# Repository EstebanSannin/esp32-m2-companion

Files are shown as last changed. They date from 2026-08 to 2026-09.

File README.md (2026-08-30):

<p align="center">
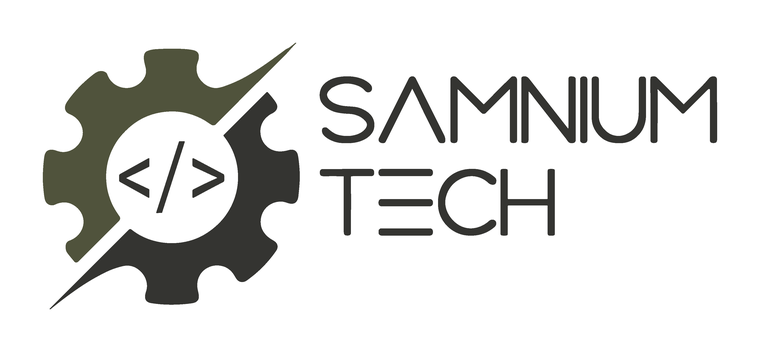
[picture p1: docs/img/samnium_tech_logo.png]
Samnium Tech
  
</p>

# esp32-m2-companion

M.2 Key-B 2242 card with an ESP32-S3-WROOM-1 acting as a USB companion MCU
for embedded Linux hosts. Spec: [SPEC.md](SPEC.md) (contract, frozen v1).

<p align="center">
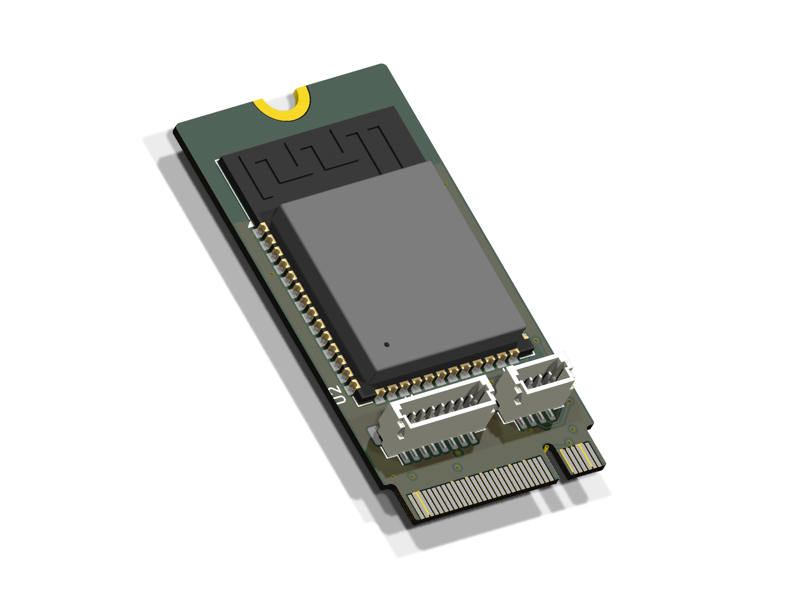
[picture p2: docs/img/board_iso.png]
3D render of the routed card
  
</p>
<p align="center"><sub>
  Generated render of the routed board · <a href="docs/img/board_top.png">top</a> ·
  <a href="docs/img/board_bottom.png">bottom</a> (silk logo) · regenerate with <code>make render</code>
</sub></p>

**[→ Product datasheet](DATASHEET.md)** — features, specs, pinout, recovery interface.
**[→ Layer stackup & routing](docs/stackup.md)** — 4-layer stack, impedance, per-layer copper views.
**[→ Interactive 3D viewer](https://estebansannin.github.io/esp32-m2-companion/3d/viewer.html)**
(GitHub Pages; or download [docs/3d/viewer.html](docs/3d/viewer.html) — fully
offline, GLB embedded) · [STEP](docs/3d/esp32_m2_companion.step) /
[GLB](docs/3d/esp32_m2_companion.glb) for MCAD · regenerate with `make 3d`.

**Open source hardware** — © 2026 Stefano Viola, licensed under
[CERN-OHL-P v2](LICENSE). Designed by Stefano Viola with Claude (Anthropic);
schematic-as-code in SKiDL, all outputs generated (`make check`, `make sch`,
`make svg`). The vendored M.2 card-edge footprint derives from
[timonsku/M.2-Card-Footprints](https://github.com/timonsku/M.2-Card-Footprints)
(CERN-OHL-P v2).

Current phase: **Phase 2 — Layout** (GATEs 1–2 passed). Owner routes
[hardware/kicad/esp32_m2_companion.kicad_pcb](hardware/kicad/esp32_m2_companion.kicad_pcb);
open items in [docs/layout-notes.md](docs/layout-notes.md).

## Host compatibility

| Host | Status |
|---|---|
| Toradex Mallow (Verdin) M.2 Key-B slot | Primary target — pin mapping verified against Mallow V1.1 datasheet |
| Raspberry Pi 5 + Waveshare "PCIe TO 4G/5G M.2 USB3.2 HAT+" | Nice-to-have (ADR 0004) — HAT officially fits 3042/3052 (2242 standoff TBD), sideband wiring unpublished |
| Raspberry Pi official M.2 HAT+ | **NOT compatible** — M-key, PCIe only, no USB on the socket |

## Layout

- `docs/datasheets/` — all reference documents (provenance in its README)
- `docs/pinmap.md` — M.2 edge + ESP32-S3 pin allocation (GATE 1)
- `docs/decisions/` — ADRs
- `docs/risks.md` — risk register
- `docs/environment.md` — tool install log
- `hardware/` — schematic-as-code + KiCad (Phase 1+)
- `firmware/` — ESP-IDF project (Phase 4)

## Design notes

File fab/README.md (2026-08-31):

# Fab package — JLCPCB upload files

Generated by `make fab` (regenerates from the routed board). Upload these 3 to
JLCPCB's [instant quote](https://cart.jlcpcb.com/quote):

| File | JLCPCB slot |
|---|---|
| `esp32_m2_companion_gerbers.zip` | **Gerber file** (PCB tab) |
| `esp32_m2_companion_bom_jlc.csv` | **BOM** (SMT Assembly tab) — Comment / Designator / Footprint / LCSC# |
| `esp32_m2_companion_cpl_jlc.csv` | **CPL / centroid** (SMT Assembly tab) — 22 placed parts |

## Order settings (v1) — confirmed against JLCPCB quote UI 2026-08-30
- **Layers 4**, thickness **0.8 mm**
- **Specify Stackup: Yes → JLC04081H-3313** (Standard, 0.80 mm, prepreg 3313
  RC57% 0.0994 mm). This alone locks the geometry that sets the USB impedance.
- **Impedance Control: No requirement** (i.e. OFF). Deliberate: JLC charges
  ~€28 for it, and the ESP32-S3 USB is Full-Speed (12 Mbps) only — controlled
  impedance is functionally irrelevant. The stackup spec above already pins the
  0.0994 mm prepreg, and the verified 0.14 mm traces give ~88 Ω regardless
  (see docs/stackup.md). The paid option only buys a TDR measurement, not a
  different board.
- Surface finish **ENIG**.
- **Gold Fingers: Yes** (hard gold on the M.2 edge contacts — accepted at our
  size, no visible upcharge; proper wear finish for a plug-in edge).
- **Beveling: No** — forced. JLC UI: *"Beveled fingers cannot be produced for
  PCBs smaller than 50mm x 50mm."* Our card is 22×42. **Consequence:** square
  90° finger edge. Before first insertion, lightly **hand-chamfer the leading
  edge** (~45°, ~0.2–0.3 mm, both faces, leading corner only — do not sand the
  contact tips) so it seats without stressing the host M.2 socket.
- Confirm Production File: **Yes**; Deburring/Edge rounding: Yes; Mark: Remove.
- **Assembly: both sides**, 5 pcs
- 7 Extended parts (feeder fee ~$3 each): U2 module, U1 USBLC6 (ST C7519), D1/D2 BAT54A, J3/J4 JST SH
- DNP (not placed): R5, R6, C8, C9 — already excluded from the CPL

Do not order before GATE 3 (colleague review). See docs/layout-notes.md, docs/review-findings.md.

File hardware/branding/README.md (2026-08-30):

# Branding — silkscreen label

Bottom-side silk label placed in the top strip of the card (under the M.2
mounting hole, above C6/C7 — a component-free area).

- `logo_samnium_tech.png` — source logo (samnium.tech, `logo_samnium_tech_no_bg_no_name.png`,
  3167×1255, fetched 2026-08-30). Owner-supplied company logo.
- `gen_logo_silk.py` — crops the gear logomark (drops the wordmark), thresholds
  to 1-bit, emits `logo_silk_rects.json` (run-length silk rectangles, ~3.8×4 mm).
  Run: `uv run --no-project --with pillow python hardware/branding/gen_logo_silk.py`
- `logo_silk_rects.json` — committed so the silk is regenerable without Pillow.
- Applied to the board by `../tools/add_silk.py` (grouped as `silk_label`,
  idempotent — safe to re-run; never touches copper/routing).

Text lines: `ESP32-M2-COMPANION` / `v1.0  Stefano Viola` / `2026-08` (0.8 mm).

Note: the diagonal brand slash is ~0.1–0.15 mm at 3.8 mm — at silk's limit, may
print faint. The gear teeth and `</>` are above the 0.15 mm floor.

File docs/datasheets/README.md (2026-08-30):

# Datasheet provenance

All pin assignments in `docs/pinmap.md` trace to these files. Fetched
2026-08-28 unless noted.

| File | Source URL | Version | Used for |
|---|---|---|---|
| `mallow-carrier-board-datasheet.pdf` | https://docs.toradex.com/113873-mallow-carrier-board-datasheet.pdf | Mallow V1.1 datasheet | **Primary host.** M.2 X17 pin table (Table 10, pp. 15–17), X16 secondary extension header (Table 22, pp. 27–28), USB hub topology (§2.5.2), power rails (Table 4) |
| `esp32-s3-wroom-1_wroom-1u_datasheet_en.pdf` | https://www.espressif.com/sites/default/files/documentation/esp32-s3-wroom-1_wroom-1u_datasheet_en.pdf | v1.8 | Module pin definitions (Table 3-1, pp. 11–12), strapping pins (§4, pp. 13–14), variant comparison (Table 1-1, p. 3) |
| `esp32-s3_hardware_design_guidelines_en.pdf` | https://docs.espressif.com/projects/esp-hardware-design-guidelines/en/latest/esp32s3/esp-hardware-design-guidelines-en-master-esp32s3.pdf | release `master` (rolling) | EN/CHIP_PU reset timing + RC (10 kΩ/1 µF) §1.3.3, decoupling & 4-layer power layout, antenna keep-out |
| `quectel_rm50xq_hardware_design_v1.2.pdf` | https://sixfab.com/wp-content/uploads/2022/05/Quectel_RM50xQ_Series_Hardware_Design_V1.2.pdf | V1.2 (2022-01-27) | **M.2 Key-B WWAN socket pinout reference** (Figure 2 p. 22, Table 8 pp. 23+). The PCI-SIG M.2 EM spec is paywalled; this is the canonical WWAN-card usage of the socket, cross-checked pin-for-pin against Mallow Table 10 |
| `usblc6-2sc6.pdf` | https://media.digikey.com/pdf/Data%20Sheets/UTD%20Semi%20PDFs/USBLC6-2SC6.pdf | UMW (友台) clone datasheet | USBLC6-2SC6 pinout/ratings. **NOT the ST original** — st.com and mouser.com are blocked from this machine. Pin-compatible; UMW part is itself an LCSC BOM candidate (C323793). Owner to supply ST original if ST part (LCSC C7519) is chosen |
| `waveshare_pcie-to-4g5g-m2-usb32-hatplus_wiki_snapshot.html` | https://www.waveshare.com/wiki/PCIe_TO_4G/5G_M.2_USB3.2_HAT+ | wiki snapshot | Secondary host (RPi5 HAT). **No board schematic is published.** Wiki confirms: 3042/3052 module support (no 2242 standoff mentioned), onboard reset button, SIM7600-M.2 (USB2-only modem) supported ⇒ USB 2.0 D+/D− wired to socket |

## Missing / unobtainable

- **TOGIALED TJ-S1706SW6T side-view LED drawing** — LCSC datasheet mirror
  blocks direct download from this machine. Needed at GATE 3 for the land
  pattern + emitting-face orientation (currently 0603 placeholder). Grab it
  from the LCSC product pages (C273612 / C273616) in a browser.

- **ST USBLC6-2 original datasheet** — st.com unreachable from here.
- **Waveshare HAT+ schematic** — not published; M.2 sideband wiring on that
  board is unknown (recovery there is best-effort per SPEC §10.6).
- **PCI-SIG M.2 (NGFF) electromechanical spec** — paywalled; mechanical
  card-outline data for Phase 2 will need a licensed copy or a derived
  reference (flagged for GATE 1).

## Added during Phase 2 (2026-08-28)

| File | Source URL | Used for |
|---|---|---|
| `amphenol_mdt420b01001_m2_socket.pdf` | via JLCPCB part page C4594496 (Amphenol ICC product brief) | Mallow's M.2 socket: ratings, durability. NOTE: no mating-card drawing — product brief only |
| `m2_em_spec_rev1.0_2013_archive.pdf` | archive.org copy (via timonsku/M.2-Card-Footprints README) of PCI-SIG "PCIe M.2 Electromechanical Spec Rev 1.0" (2013) | Card mechanical geometry: 2242 outline, gold-finger dimensions, notch position, bevel. Rev 1.0 (current spec is newer) — fine for mechanical card data; resolves risk R8 |
| `togialed_tj-s1706_sideview.pdf` | LCSC datasheet repository (C273616) | D3/D4 side-view LED land pattern (0.80×0.70, 1.80 mm c-c), polarity (pin 1 = cathode), package geometry. Drove the custom `LED_TJ-S1706_SideView` footprint |

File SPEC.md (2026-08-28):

# ESP32-S3 M.2 Companion Card — Project Specification (v1.0)

Project codename: `esp32-m2-companion`
Owner: Stefano · Design agent: Claude (Claude Code session)
Status: spec frozen for v1 — changes require owner approval

---

## 1. Concept

A small M.2 Key-B 2242 card carrying an ESP32-S3 module, acting as a
**companion microcontroller** for embedded Linux hosts. The host talks to it
over the USB 2.0 lines available on the M.2 connector; the card offloads
realtime / GPIO / sensor work the Linux side is bad at. WiFi/BLE come for free
from the module.

Design philosophy: **hardware-as-code**. Schematic captured in a code-based
tool, verified with headless ERC/DRC, versioned in git, reviewed by the owner
at defined gates before any money is spent.

## 2. Goals (v1)

- G1. Enumerate as a USB CDC device on the host immediately after insertion.
- G2. Firmware fully replaceable **from the host**, including recovery of a
  bricked card, with no physical button access.
- G3. Expose usable IO on a card-edge header: GPIO, I2C, UART, SPI-capable pins.
- G4. Status LED controllable from firmware + power indicator LED.
- G5. WiFi/BLE functional via the module's integrated antenna (best-effort in
  v1: correct keep-out and placement, no formal RF validation).
- G6. Fully assembled by JLCPCB (SMT service); owner only plugs it in.
- G7. Reusable block structure so a radio-less RP2350 sibling card can be
  derived later by swapping only the MCU block.

## 3. Non-goals (v1)

- No PCIe, no SATA, no SIM interface.
- No battery, no external power input: card is powered only from M.2 3.3V.
- No RF certification work, no antenna tuning.
- No enclosure / thermal design.
- No level shifting beyond 3.3V IO (hosts with 1.8V GPIO banks interact via
  USB, not via the header).

## 4. Target hosts

| Host | Slot | Status |
|---|---|---|
| Toradex Mallow carrier (Verdin family) | On-board M.2 Key-B, 30/42/52 mm cards, intended for modems | Primary target. **Verify from datasheet** which pins carry USB 2.0 and which sideband signals (W_DISABLE#, RESET#, FULL_CARD_POWER_OFF#, …) are wired to SoM GPIOs. Datasheet: https://docs.toradex.com/113873-mallow-carrier-board-datasheet.pdf |
| Raspberry Pi 5 + third-party Key-B modem HAT (e.g. Waveshare "PCIe to M.2 4G/5G + USB 3.2 HAT") | Key-B slot with USB wired (modem slot) | Secondary target. Official RPi M.2 HAT+ is M-key/PCIe-only → NOT compatible, document this clearly in README. **Verify** the chosen HAT provides USB 2.0 (not only USB 3) on the socket and has a standoff position at 42 mm. |

## 5. Form factor & fabrication constraints

- M.2 module, **Key B**, size **2242** (22 × 42 mm), single-sided component
  placement on top preferred (bottom side allowed for passives if needed —
  check socket clearance class in M.2 spec).
- PCB thickness **0.8 mm** (M.2 requirement — not 1.6 mm!).
- Edge connector: gold fingers per M.2 spec geometry, **ENIG/hard-gold finger
  option + 45° edge bevel** must be selected at JLCPCB order time. Confirm
  JLCPCB supports gold fingers on 0.8 mm 4-layer — adjust stackup if not.
- Layer count: 4 layers (SIG / GND / PWR / SIG) — makes USB diff-pair
  referencing and RF keep-out trivial; cost difference at JLCPCB is small.
- Design rules: JLCPCB standard capability (≥ 5/5 mil trace/space to be safe,
  ≥ 0.3 mm drill, their published rules imported into KiCad as DRC profile).
- All components chosen from **LCSC catalog**, preferring JLCPCB **Basic
  parts**; every Extended part must be flagged in the BOM with justification.
- Card mounting notch centered at top edge per M.2 mechanical drawing.

## 6. Hardware architecture

### 6.1 MCU
- **ESP32-S3-WROOM-1-N8R2** (8 MB flash, 2 MB PSRAM). If N8R2 has poor LCSC
  stock, N8 or N16R8 acceptable — flag for approval.
- Module PCB antenna located at the **top card edge** (away from the M.2
  connector), with copper/ground keep-out under the antenna area per
  Espressif's hardware design guidelines. Antenna may overhang the 42 mm edge
  only if the mounting standoff geometry still works — otherwise inboard with
  keep-out.

### 6.2 Power
- 3.3V taken directly from M.2 3.3V rail (rated for modem-class loads —
  budget ≥ 1 A available; ESP32-S3 WiFi TX bursts ~500 mA peak).
- **No regulator in v1.** Input filtering: ferrite bead or 0Ω + bulk
  (≥ 2 × 22 µF ceramic or 47–100 µF) + per-pin 100 nF decoupling per
  Espressif guidelines.
- Power LED (green) on 3.3V rail with suitable series resistor.

### 6.3 USB
- M.2 USB 2.0 D+/D− routed directly to ESP32-S3 native USB pins
  (GPIO19/GPIO20). Pin numbers of USB on the Key-B edge connector must be
  taken from the **M.2 specification pinout, verified against the Mallow
  datasheet** — never from memory.
- 90 Ω differential pair routing, length-matched, solid ground reference,
  no stubs. USB-FS (12 Mbps) is forgiving but do it properly.
- ESD protection: USBLC6-2SC6 or equivalent LCSC-stocked TVS array on D+/D−,
  placed close to the edge connector.

### 6.4 Host-controlled recovery (critical requirement)
- ESP32-S3 **EN** and **GPIO0 (BOOT)** each wired to an M.2 sideband pin
  (candidates: RESET#, W_DISABLE1#, FULL_CARD_POWER_OFF# — final choice
  driven by what Mallow actually wires to SoM GPIOs and what the RPi HAT
  exposes; document the mapping).
- Sideband inputs treated as open-drain with on-card pull-ups to 3.3V, so an
  unconnected sideband = normal boot. RC on EN per Espressif reset timing.
- Resulting recovery flow (document in README):
  `host gpioset BOOT=0, pulse EN` → ROM bootloader → `esptool.py` over the
  same USB → flash → release. Normal flow: esptool auto-reset over
  USB-Serial-JTAG, no GPIO needed.

### 6.5 Status LED
- One firmware-controlled LED on a module GPIO (active-low, series resistor).
  Optional (owner may approve): WS2812B-2020 instead, single data GPIO.

### 6.6 IO header
- 2.54 mm pitch, single row, along the long card edge (top side), **unpopulated**
  (JLCPCB assembles SMD; owner can solder a header when needed — or select
  their through-hole assembly if trivial).
- Signals (~12 pins): 3.3V, GND, 1× I2C (SDA/SCL with footprints for optional
  pull-ups, DNP by default), 1× UART (TX/RX), 4–6 × GPIO chosen so that at
  least one full SPI set is available among them. Choose GPIOs avoiding
  strapping pins and octal-PSRAM-reserved pins (GPIO35-37 on R8 variants —
  check per chosen module variant).
- Silkscreen label every pin.

### 6.7 Things deliberately absent
- No USB-C debug connector (host USB is the debug port). If layout has spare
  room, test points for EN/BOOT/TX/RX/3V3/GND are welcome.

## 7. Firmware (v1 bring-up)

ESP-IDF (latest stable) project in `firmware/`:
- USB CDC console (USB-Serial-JTAG) with a trivial command shell:
  `led on|off|blink`, `gpio read|write <n>`, `i2cdetect`, `info` (chip ID,
  reset reason, firmware version).
- Blink task on the status LED as heartbeat.
- WiFi station connect + `ping` demo behind a config flag (proves radio).
- Makefile/justfile targets: `build`, `flash` (esptool over /dev/ttyACMx),
  `recover-flash` (gpioset sequence documented per host).

## 8. Toolchain & environment

- Work happens on the owner's server (`m920x`), account already provisioned.
  Claude may install tools (apt/pip) as needed — keep an
  `docs/environment.md` log of everything installed.
- **KiCad 9** + `kicad-cli` for headless ERC/DRC/exports.
- Schematic-as-code: **atopile** preferred; fall back to **SKiDL** if atopile's
  component/footprint availability blocks progress. Decision documented in
  `docs/decisions/0001-hdl-tool.md` (keep ADRs for major choices).
- Layout: interactive work is the owner's; Claude prepares placement
  suggestions, net classes (USB diff pair 90 Ω), DRC profile, and reviews the
  routed board by parsing the `.kicad_pcb` file.
- JLCPCB DRC rule set imported; CI (even a simple `make check`) runs
  ERC + DRC + BOM-vs-LCSC availability check on every commit.
- Outputs for ordering: Gerbers (JLCPCB naming), drill files, BOM (LCSC part
  numbers), CPL/pick-and-place, assembly drawings.

## 9. Workflow & review gates

Claude works autonomously **within a phase**, stops at every gate for owner
review. Never proceed past a gate without explicit approval.

- **Phase 0 — Groundwork.** Fetch and store in `docs/datasheets/`: Mallow
  datasheet, ESP32-S3-WROOM-1 datasheet, ESP32-S3 hardware design guidelines,
  M.2 (NGFF) Key-B pinout reference, USBLC6 datasheet, candidate RPi5 HAT
  wiki/schematic. Produce `docs/pinmap.md`: full M.2 edge-pin table (pin,
  M.2 spec function, Mallow wiring, our usage) + ESP32-S3 pin allocation
  table (pin, function, strapping notes). → **GATE 1: owner reviews pinmap.**
- **Phase 1 — Schematic-as-code.** Implement blocks: `m2_connector`, `power`,
  `usb_esd`, `mcu`, `recovery`, `leds`, `header`. ERC clean. Netlist + BOM
  (all LCSC-resolved) + human-readable schematic PDF export.
  → **GATE 2: owner reviews schematic + BOM.**
- **Phase 2 — Layout.** Claude: board outline with exact M.2 2242 mechanical
  geometry + gold-finger footprint, placement proposal, net classes, DRC
  profile. Owner routes / adjusts in KiCad GUI; Claude reviews the result
  (DRC, diff-pair check, antenna keep-out check, silkscreen review).
  → **GATE 3: owner approves layout.**
- **Phase 3 — Fab package.** Gerbers/BOM/CPL, JLCPCB order checklist
  (0.8 mm, 4-layer, gold fingers + bevel, assembly side, part substitutions).
  → **GATE 4: owner places order.**
- **Phase 4 — Firmware & bring-up plan.** Firmware ready before boards
  arrive; `docs/bringup.md` = step-by-step first-power checklist (visual
  inspection, resistance checks on 3.3V, first insertion in Mallow, dmesg
  expectations, flash, LED, I2C scan, WiFi test).

## 10. Success criteria

1. Card inserted in Mallow → host `dmesg` shows Espressif USB-Serial-JTAG
   CDC device.
2. `esptool.py` flashes firmware over that port.
3. Bricked-firmware simulation (flash garbage) → recovered purely via host
   GPIO sequence + esptool.
4. Status LED heartbeat; `i2cdetect` finds a sensor wired to the header.
5. WiFi demo connects to an AP.
6. Same result on RPi5 + chosen Key-B HAT (best effort).

## 11. Known risks / open questions (track in `docs/risks.md`)

- R1. Mallow B-key USB wiring & sideband→SoM GPIO mapping unconfirmed until
  datasheet is read. (Blocks pinmap.)
- R2. JLCPCB gold fingers + bevel on 0.8 mm 4-layer: confirm capability/cost.
- R3. Antenna performance flat against a carrier board: accepted risk in v1.
- R4. 2242 card mechanical fit in 3042-oriented RPi HATs (standoff position).
- R5. GPIO choice vs. octal-PSRAM reservations on the exact WROOM variant.

## 12. Knowledge management (added 2026-08-28, owner)

1. `docs/review-findings.md` is an **append-only** log. Every finding from any
   review gate — owner's, an external senior HW designer's, or self-caught —
   gets one entry: date, phase, finding, severity, and a classification:
   - **BLOCK**: bug/improvement in a reusable circuit block → fix the block
     source and add a line to that block's `LESSONS.md`
   - **PROCESS**: workflow/tooling/fab gap → flag to owner as a candidate rule
     for the shared hardware-design skill
   - **PROJECT**: specific to this board → note it in `CLAUDE.md`
2. Schematic sources are organized as self-contained reusable blocks
   (`m2_keyb_edge`, `esp32s3_companion`, `usb_esd`, `power_3v3`, `leds`,
   `io_header`) — each block in its own directory with sources, datasheet
   references, and a `LESSONS.md` (empty is fine; the file must exist). At
   project end, stable blocks are promoted to a shared hw-blocks repo.
3. `CLAUDE.md` stays current with project conventions: net names follow the
   M.2 / Verdin datasheet naming verbatim, tool choices, DRC profile, gate
   protocol.
4. When the owner relays findings from an external senior designer review,
   their categorization ("wrong" / "works but unprofessional" / "fragile at
   scale") is preserved in the log — never flattened.

---

# Kickoff prompt for the Claude Code session

Copy-paste the following as the first message (with SPEC file placed in the
repo root as `SPEC.md`):

```
You are the hardware design engineer for this project. Read SPEC.md fully
before doing anything — it is the contract; do not deviate from it without
asking me.

Context: we are designing an M.2 Key-B 2242 card with an ESP32-S3 acting as
a USB companion MCU for embedded Linux hosts (details in SPEC.md). I am an
experienced embedded engineer; talk to me as a peer, be concise, and
challenge the spec if you find a real problem in it.

Ground rules:
1. Work phase by phase as defined in SPEC.md §9. STOP at every GATE and ask
   for my review. Within a phase, work autonomously.
2. Never trust memory for pinouts, footprints or electrical values. Every
   pin assignment must be traceable to a datasheet stored in
   docs/datasheets/. If a document can't be fetched, tell me and I'll
   provide it.
3. Everything in git: small commits, meaningful messages. Record notable
   choices as short ADRs in docs/decisions/.
4. You may install any tools you need on this machine (KiCad 9, kicad-cli,
   atopile, skidl, esp-idf, python packages). Log installs in
   docs/environment.md.
5. Every BOM line must carry an LCSC part number and Basic/Extended status.
6. After any change to schematic sources, run ERC headlessly and show me
   the result. Set this up as `make check` early.
7. If you are uncertain between two design options, present both with a
   recommendation instead of silently picking one.

Start now with Phase 0: create the repo skeleton, fetch the datasheets
listed in SPEC.md §9 Phase 0, and produce docs/pinmap.md for GATE 1 review.
```

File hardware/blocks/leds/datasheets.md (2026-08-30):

# References — leds
- ADR 0003 (+ 2026-08-29 amendment: side-view at left card edge).
- D3: TOGIALED TJ-S1706SW6TGLC2G-A5 green side-view (LCSC C273616, Extended)
- D4: TOGIALED TJ-S1706SW6TGLC2R-A5 red side-view (LCSC C273612, Extended)
- R3/R4: 330R 0603 (C23138, Basic). Green InGaN Vf(20mA) 2.8–3.4 V → runs
  ~1–2 mA at 3.3 V by design; red ~3.5 mA. Verify brightness at bring-up.
- KiCad Device:LED pin 1 = K, pin 2 = A. **RESOLVED 2026-08-30** against the
  TOGIALED datasheet (`docs/datasheets/togialed_tj-s1706_sideview.pdf`):
  - Land pattern was a 0603 placeholder (1.576 mm c-c) — too tight for the
    1.70 mm body. Replaced with custom `LED_TJ-S1706_SideView` footprint
    (pads 0.80×0.70, **1.80 mm c-c** per datasheet). DRC clean; LED-net
    connectivity preserved (old track ends stay inside the new pads).
  - Polarity confirmed: pin 1 = cathode (black-mark end, diode symbol),
    pin 2 = anode — matches KiCad Device:LED and our netlist.
  - Emit face marked on F.Fab pointing −x (out the left card edge). Caveat:
    the datasheet 2D views do NOT distinguish the two long faces, so the
    front/back emit face is the *intended* direction — **confirm on a
    physical sample at GATE 3** (low risk: 120° beam + edge placement).

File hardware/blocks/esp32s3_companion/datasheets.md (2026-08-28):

# References — esp32s3_companion
- docs/datasheets/esp32-s3-wroom-1_wroom-1u_datasheet_en.pdf v1.8
  (Table 3-1 pins, §4 strapping, Table 1-1 variants)
- docs/datasheets/esp32-s3_hardware_design_guidelines_en.pdf (decoupling)
- KiCad symbol RF_Module:ESP32-S3-WROOM-1 (pin names runtime-asserted
  against Table 3-1 in esp32s3_companion.py)

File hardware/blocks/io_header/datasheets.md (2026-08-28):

# References — io_header
- SPEC §6.6; docs/pinmap.md §2 (GPIO selection rationale)
- Unpopulated (DNP). I2C pull-up footprints 10k DNP.

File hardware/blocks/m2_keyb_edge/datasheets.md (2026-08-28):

# References — m2_keyb_edge
- docs/pinmap.md §1 (authoritative pin table for this block)
- docs/datasheets/mallow-carrier-board-datasheet.pdf Table 10 (X17)
- docs/datasheets/quectel_rm50xq_hardware_design_v1.2.pdf Fig. 2 / Table 8
- Footprint: placeholder `esp32m2:M2_KeyB_2242_EdgeFingers` — Phase 2, needs
  M.2 EM spec gold-finger geometry (risk R8)

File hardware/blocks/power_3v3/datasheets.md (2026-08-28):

# References — power_3v3
- SPEC §6.2; Espressif HDG power sections
- FB: Sunlord GZ2012D101TF (LCSC C1015, Basic) 100R@100MHz, 800 mA, 150 mR.
  Chosen over GZ2012D601TF (C1017): that one is 500 mA — too close to
  ESP32-S3 TX bursts. Alternative if bead rejected at GATE 2: 0R link.

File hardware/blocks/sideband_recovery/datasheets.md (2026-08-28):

# References — sideband_recovery
- ADR 0002 (mapping + SODIMM 244 device-tree evidence)
- docs/datasheets/lbat54a_schottky.pdf (BAT54A: pin 3 = common anode —
  note the doc TITLE wrongly says "Dual Series"; trust the drawing)
- docs/datasheets/esp32-s3_hardware_design_guidelines_en.pdf §1.3.3 (EN RC)

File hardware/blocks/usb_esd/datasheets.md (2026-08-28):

# References — usb_esd
- docs/datasheets/usblc6-2sc6.pdf (UMW clone doc; pin map p.1 —
  1=I/O1 2=GND 3=I/O2 4=I/O2 5=VBUS 6=I/O1). ST original pending (risk R7).

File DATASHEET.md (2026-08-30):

# ESP32 M.2 Companion — Datasheet

**M.2 Key-B 2242 USB companion microcontroller card**
Preliminary · rev `c5e5aa7-dirty` · 2026-08-31 · © 2026 Stefano Viola · CERN-OHL-P v2
*(generated by `make datasheet` — do not edit by hand)*

<p align="center">3D render</p>

The card adds a fully host-controlled ESP32-S3 to any embedded Linux system
with an M.2 Key-B socket: it enumerates as a USB CDC device, is flashable and
even brick-recoverable purely from the host, and offloads realtime GPIO /
I2C / SPI / UART work — with Wi-Fi and Bluetooth LE included. Primary host:
Toradex Verdin family (Mallow carrier).

## Features

- **MCU**: ESP32-S3-WROOM-1-N8R2 — Xtensa dual-core 32-bit LX7 @ 240 MHz,
  single-precision FPU, 512 KB SRAM + 16 KB RTC SRAM, 384 KB ROM
- **Memory**: 8 MB quad-SPI flash, 2 MB quad-SPI PSRAM (in module)
- **Radio**: Wi-Fi 4 (802.11b/g/n, 2.4 GHz, up to 150 Mbps, up to
  20.5 dBm TX) · Bluetooth 5 LE + mesh · on-module PCB antenna
- **Host link**: USB 2.0 full-speed on the M.2 edge, native USB-Serial-JTAG
  → CDC console, `esptool` flashing, and JTAG debugging with zero extra parts
- **Host-controlled recovery**: reset (EN) and boot-strap (IO0) on M.2
  sideband pins, Schottky-isolated — a bricked card is reflashed entirely
  from the host, no buttons, no cables
- **IO**: Qwiic/STEMMA-QT I2C port (JST SH-4) + UART/SPI/GPIO port
  (JST SH-8), 3.3 V logic
- **Form factor**: M.2 Key-B 2242 (22 × 42 mm, 0.8 mm PCB, 4-layer),
  single 3.3 V supply from the slot
- **Open source hardware** (CERN-OHL-P v2), schematic-as-code (SKiDL),
  assembled by JLCPCB

## Block diagram

```mermaid
flowchart LR
    subgraph HOST["Linux host (M.2 Key-B slot)"]
        USB["USB 2.0 FS"]
        GPIOs["2x sideband GPIO"]
        PWR["3.3 V"]
    end
    subgraph CARD["esp32-m2-companion"]
        ESD["USBLC6-2 ESD"]
        DIODE["Schottky isolation"]
        FB["Ferrite + bulk"]
        MCU["ESP32-S3-WROOM-1\n(USB-Serial-JTAG)"]
        LED["2x LED"]
        J3["J3 Qwiic I2C"]
        J4["J4 UART/SPI/GPIO"]
    end
    USB <--> ESD <--> MCU
    GPIOs --> DIODE -->|EN / IO0| MCU
    PWR --> FB --> MCU
    MCU --> LED
    MCU <--> J3
    MCU <--> J4
```

## Specifications

| Parameter | Value | Source |
|---|---|---|
| Supply voltage | 3.3 V ±5 % from M.2 edge (no on-card regulator) | SPEC §6.2 |
| Supply current | ~95 mA Wi-Fi RX · ~355 mA avg TX @ 20.5 dBm (bursts higher) · design budget 500 mA | WROOM DS Table 6-4 |
| Host interface | USB 2.0 full-speed (12 Mbps), CDC-ACM via USB-Serial-JTAG | WROOM DS §Pin Definitions |
| Logic level (IO ports) | 3.3 V (not 5 V tolerant) | ESP32-S3 DS |
| Wi-Fi | 802.11b/g/n 2.4 GHz (2412–2484 MHz), ≤150 Mbps, ≤20.5 dBm | WROOM DS §7.1 |
| Bluetooth | 5 (LE) + mesh, ≤20 dBm | WROOM DS §7.2 |
| Operating temperature | −40 … +85 °C (module limit) | WROOM DS Table 1-1 |
| Dimensions | 22 × 42 mm (M.2 2242), 0.8 mm PCB | M.2 EM spec |
| Height (top) | 4.2 mm max (JST headers; module 3.1 mm) — ≈6.3 mm with SH plug mated | JST eSH catalog |
| Height (bottom) | ≤1.5 mm — within the 2.54 mm B-side allowance of an H4.2 socket | M.2 EM spec Fig 38 |
| ESD (USB lines) | IEC 61000-4-2 level 4 (USBLC6-2SC6) | ST/UMW DS |

> **Height note**: the module (3.1 mm) exceeds the M.2 1.5 mm top-side
> envelope. The card fits open sockets (e.g. Mallow X17, carrier bottom) but
> **not** enclosed hosts (laptops) — see `docs/risks.md` R11.

## M.2 edge interface (used pins)

Only the pins below are electrically used; the full 75-position table with
the standard WWAN mapping is in [`docs/pinmap.md`](docs/pinmap.md).

| Pin | Name (card) | Net | Function |
|---|---|---|---|
| 2 | VCC_3V3 | +3V3_M2 | 3.3 V supply in |
| 3 | GND | GND | Ground |
| 4 | VCC_3V3 | +3V3_M2 | 3.3 V supply in |
| 5 | GND | GND | Ground |
| 7 | USBH3_D_P | USBH3_D_P | USB 2.0 D+ |
| 9 | USBH3_D_N | USBH3_D_N | USB 2.0 D− |
| 11 | GND | GND | Ground |
| 20 | PCIE_1_GPIO_5 | PCIE_1_GPIO_5 | Boot-mode strap (IO0), active-low, diode-isolated |
| 27 | GND | GND | Ground |
| 33 | GND | GND | Ground |
| 39 | GND | GND | Ground |
| 45 | GND | GND | Ground |
| 50 | PERST_n | PERST_n | Card reset (EN), active-low, diode-isolated |
| 51 | GND | GND | Ground |
| 57 | GND | GND | Ground |
| 70 | VCC_3V3 | +3V3_M2 | 3.3 V supply in |
| 71 | GND | GND | Ground |
| 72 | VCC_3V3 | +3V3_M2 | 3.3 V supply in |
| 73 | GND | GND | Ground |
| 74 | VCC_3V3 | +3V3_M2 | 3.3 V supply in |

Sideband inputs are Schottky-isolated with on-card 10 kΩ pull-ups: any host
may **pull them low** (open-drain / drive-low-then-release); a host must not
hold them push-pull high below 2.8 V. Unconnected sidebands = normal boot.

### Recovery sequence (bricked firmware)

```
host: IO0-strap GPIO -> low          # M.2 pin 20 (or pin 8)
host: pulse PERST# low >= 5 ms       # M.2 pin 50
      -> ROM download mode -> esptool.py over the same USB port
host: release both (Hi-Z)            # normal boot
```

On Mallow: PERST# = SODIMM 244 (free it from the PCIe DT node);
pin 20 reaches the SoM via the X16.19 jumper. Details: ADR 0002.

## IO connectors

### J3 — Qwiic / STEMMA-QT I2C (JST SH-4, BM04B-SRSS-TB)

| Pin | Signal | Function |
|---|---|---|
| 1 | GND | Ground |
| 2 | +3V3 | 3.3 V out (card rail) |
| 3 | IO8 | I2C SDA |
| 4 | IO9 | I2C SCL |

Standard Qwiic pinout — off-the-shelf sensor cables plug in directly.
I2C pull-ups are DNP on-card (Qwiic peripherals provide their own);
footprints R5/R6 (10 k) can be fitted if needed.

### J4 — UART / SPI / GPIO (JST SH-8, BM08B-SRSS-TB)

| Pin | Signal | Function |
|---|---|---|
| 1 | TXD0 | UART0 TX (ROM console) |
| 2 | RXD0 | UART0 RX |
| 3 | IO10 | GPIO / SPI CS (FSPICS0) |
| 4 | IO11 | GPIO / SPI MOSI (FSPID) |
| 5 | IO12 | GPIO / SPI CLK (FSPICLK) |
| 6 | IO13 | GPIO / SPI MISO (FSPIQ) |
| 7 | IO14 | GPIO (FSPIWP) |
| 8 | IO21 | GPIO (RTC-capable) |

Both connectors are vertical (top-entry) 1.0 mm JST SH: plugs mate
perpendicular to the card and can be (un)plugged with the card in the slot.
UART0 doubles as the ROM bootloader console. The SPI set is the native
FSPI IOMUX group (up to 80 MHz).

## Product views

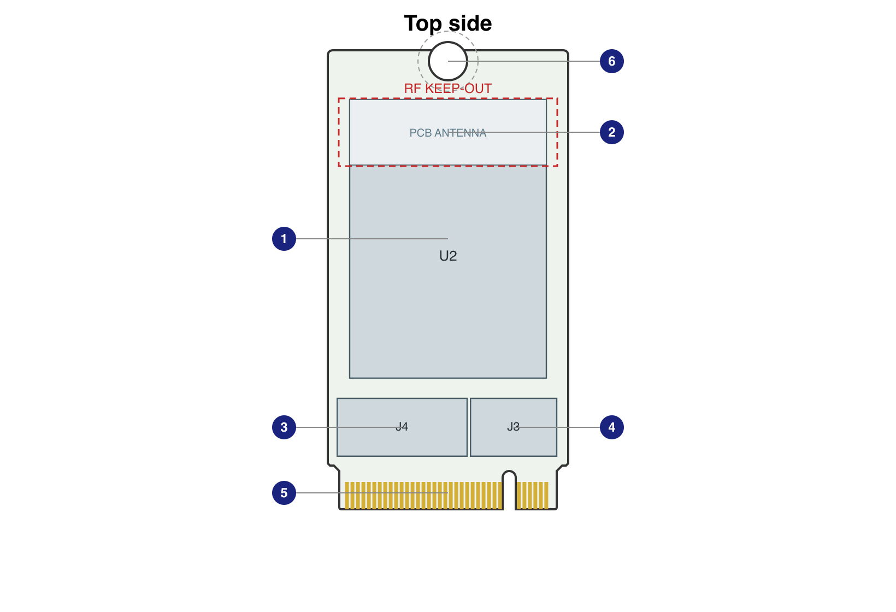
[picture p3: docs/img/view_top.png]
top view


| # | Top side |
|---|---|
| 1 | ESP32-S3-WROOM-1-N8R2 module |
| 2 | Module PCB antenna + RF keep-out zone |
| 3 | J4 - UART / SPI / GPIO (JST SH-8, top entry) |
| 4 | J3 - Qwiic / STEMMA-QT I2C (JST SH-4, top entry) |
| 5 | M.2 Key-B card edge (75-pos, USB 2.0 + sidebands) |
| 6 | Mounting notch (M.2 screw, GND pad) |

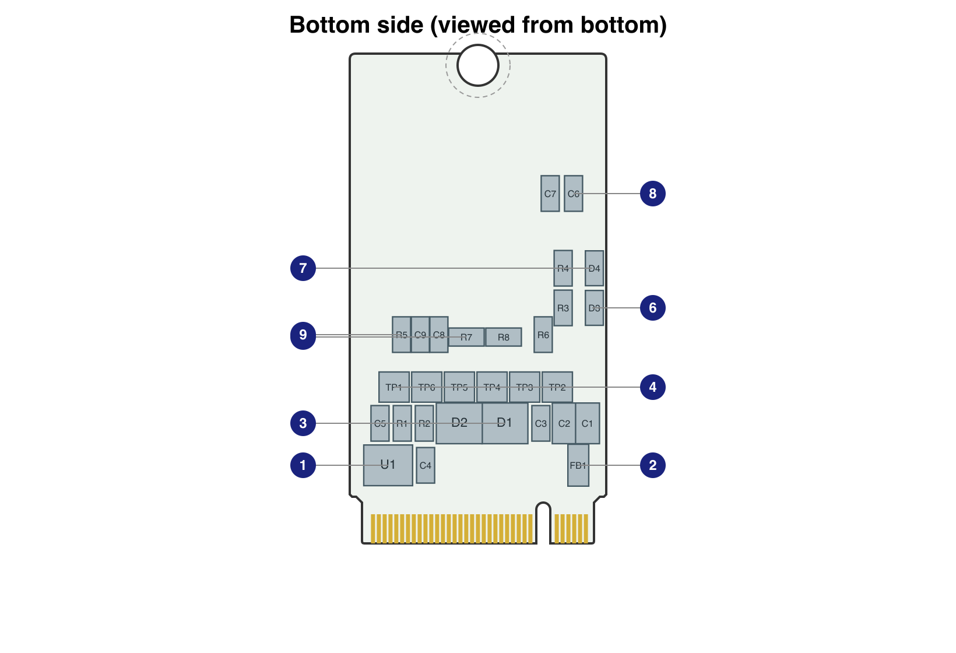
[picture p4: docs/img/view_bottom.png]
bottom view


| # | Bottom side |
|---|---|
| 1 | USBLC6-2 USB ESD protection |
| 2 | 3.3 V entry filter + bulk capacitors |
| 3 | Recovery diodes (EN / IO0 sideband isolation) |
| 4 | Test points: EN, IO0, TXD0, RXD0, 3V3, GND |
| 5 | USB series resistors (0R) |
| 6 | Power LED (green, side-view, emits from left edge) |
| 7 | Status LED (red, IO48, side-view, emits from left edge) |
| 8 | Module 3V3 decoupling |
| 9 | DNP provisions (I2C pull-ups, USB shunt C) |

## Mechanical data

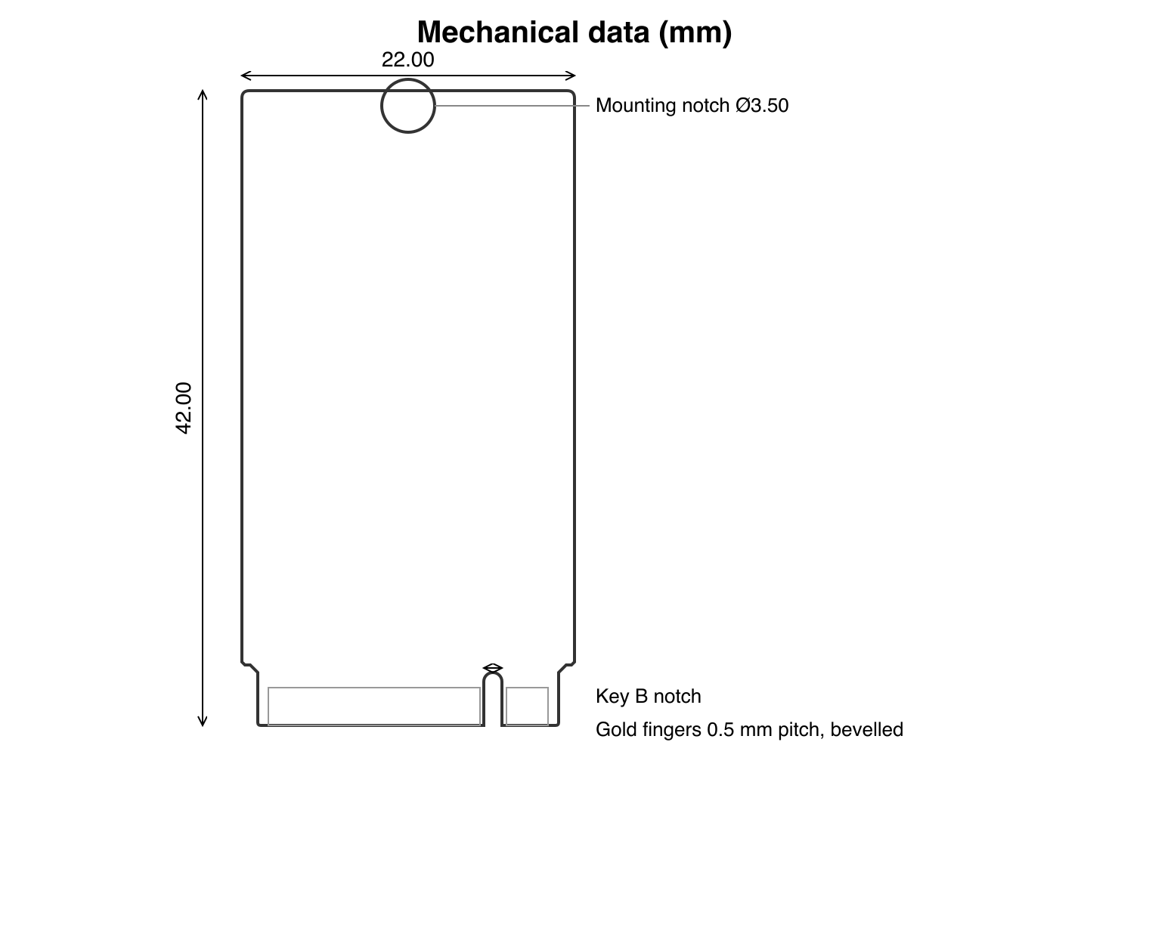
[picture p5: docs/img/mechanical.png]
mechanical drawing


| Parameter | Value |
|---|---|
| Card size | M.2 Type 2242: 22.00 × 42.00 mm |
| PCB | 0.8 mm, 4-layer (SIG/GND/PWR/SIG), ENIG + bevelled gold fingers |
| Max height, top side | 4.2 mm (JST SH headers) · ≈6.3 mm with plug mated |
| Max height, bottom side | ≤1.5 mm (compliant with H4.2 socket B-side envelope) |
| Socket coverage zone | first 4.8 mm from card edge kept component-free (both faces) |
| Mounting | M.2 screw, Ø3.5 semicircular notch, plated GND pad |
| Component sides | SMT both sides (top: module + connectors; bottom: passives) |

## LEDs & test points

| Item | Location | Function |
|---|---|---|
| Green LED (D3) | side-view, left card edge | 3.3 V rail present |
| Red LED (D4) | side-view, left card edge | firmware status, active-low on IO48 |
| TP1/TP2 | bottom | EN / IO0 (recovery without host sidebands) |
| TP3/TP4 | bottom | UART0 TX / RX |
| TP5/TP6 | bottom | 3.3 V / GND |

The LEDs are side-view parts emitting out of the left card edge — visible
with the card in the slot regardless of mounting orientation. Test points
are on the bottom side (bench use).

## Host compatibility

| Host | Status |
|---|---|
| Toradex Verdin + Mallow (X17) | Primary — verified pin mapping, recovery documented |
| Any M.2 Key-B slot with USB 2.0 | Enumerates and flashes; recovery needs 2 host GPIOs (or TPs) |
| RPi 5 + Waveshare Key-B HAT | Nice-to-have (ADR 0004) — USB works, 2242 standoff & sidebands unverified |
| Enclosed hosts (laptops/WWAN bays) | **Not compatible** — height (R11) |

## Design data

Schematic PDF (`make sch`), interactive 3D, BOM (`make check`), layout and
all sources in this repository. License: CERN-OHL-P v2.

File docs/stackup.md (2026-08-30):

# Layer stackup & routing

4-layer, 0.8 mm, **SIG / GND / PWR / SIG** — JLCPCB **JLC04081H-3313** stackup.
Layer renders below are generated from the routed board
(`hardware/kicad/esp32_m2_companion.kicad_pcb`); regenerate with `make render`
plus the per-layer export in `docs/`. Blue = copper.

## Stackup (top → bottom)

| # | Layer | Copper | Role | Notes |
|--:|---|---|---|---|
| 1 | **F.Cu** (top) | 1 oz | Signal + components | Module, JST connectors; short signal runs. Prepreg **3313, 0.0994 mm, εr 4.1** to L2 → sets the USB microstrip impedance |
| 2 | **In1.Cu** | 0.5 oz | **Solid GND plane** | Continuous reference for the USB pair; the reason the diff pair is clean. Core (NP-155F) below |
| 3 | **In2.Cu** | 0.5 oz | **+3V3 power plane** | Card 3.3 V rail (post-ferrite); every +3V3 pad vias to here |
| 4 | **B.Cu** (bottom) | 1 oz | Signal + components | Most routing; all passives, USBLC6, diodes, LEDs, test points |

- Board thickness **0.8 mm** (M.2 requirement).
- **USB pair** `USBH3_D_P/N` / `USB_D_P/N`: 90 Ω differential, **0.14 mm width /
  0.14 mm gap**, routed on the outer layers referenced to the L2 GND plane, no
  stubs (SPEC §6.3).
- **At order: Specify Stackup = `JLC04081H-3313`** (Standard, 0.80 mm, prepreg
  3313 RC57% 0.0994 mm) — *not* the 7628 default (thicker 0.72 mm "Special"
  stack). Specifying the stackup pins the 0.0994 mm prepreg, which is what sets
  the pair impedance.
- **Impedance Control QC option: left OFF** (JLC charges ~€28). The ESP32-S3 USB
  is Full-Speed (12 Mbps) only, so controlled impedance is not functional here;
  the paid option only buys a TDR measurement, not a different board.
- **Verified 2026-08-30** against JLCPCB's live impedance calculator: on
  JLC04081H-3313, 90 Ω differential (5.5 mil gap) → **5.2 mil (0.132 mm) width**.
  Our 0.14 mm traces give ~88 Ω (inside a ±10 % window) — no board change.

## The four copper layers

### 1 — F.Cu (top signal)
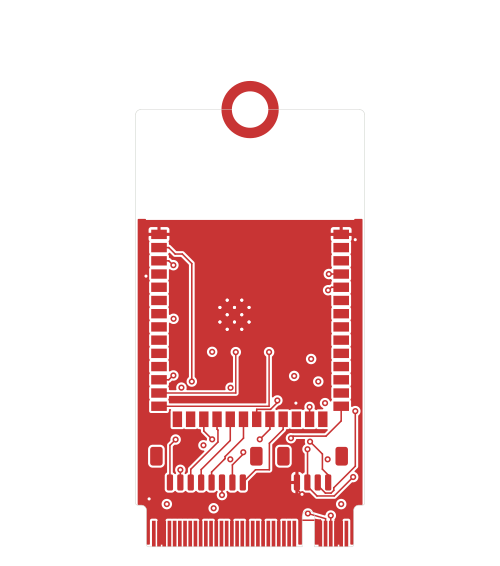
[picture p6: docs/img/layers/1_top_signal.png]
top signal


Component pads for the module (U2) and the two JST connectors (J3/J4), plus
short top-side signal segments. The dashed rectangle at the top is the antenna
keep-out (no copper under the module antenna).

### 2 — In1.Cu (GND plane)
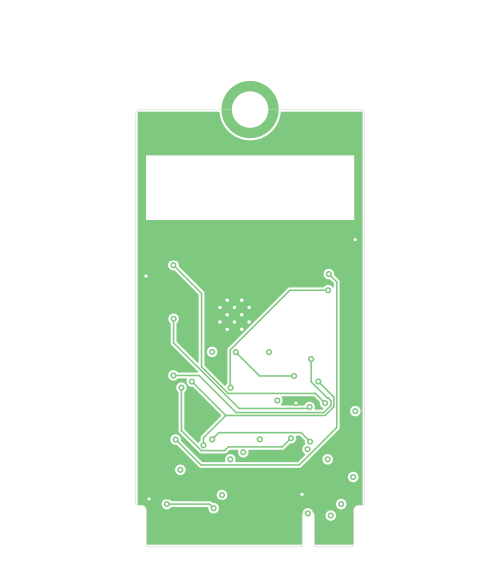
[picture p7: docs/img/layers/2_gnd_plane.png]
gnd plane


Solid ground pour — the USB pair's return-current reference. Kept continuous
under the signal layers; the antenna region is excluded.

### 3 — In2.Cu (+3V3 power plane)
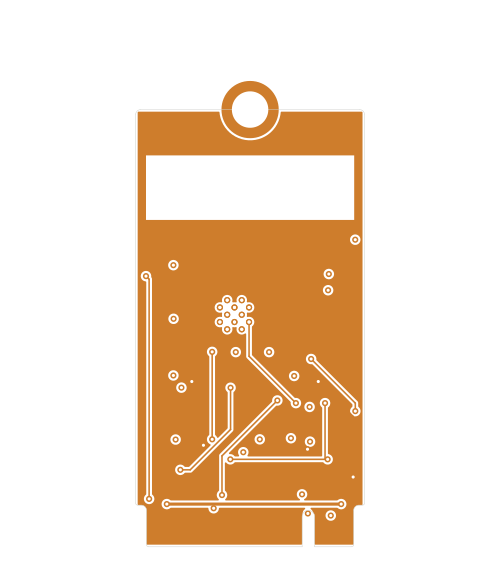
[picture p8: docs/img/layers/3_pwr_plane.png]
pwr plane


The 3.3 V card rail. Every +3V3 component pad reaches this plane through a via,
so power distribution is the plane, not surface traces.

### 4 — B.Cu (bottom signal)
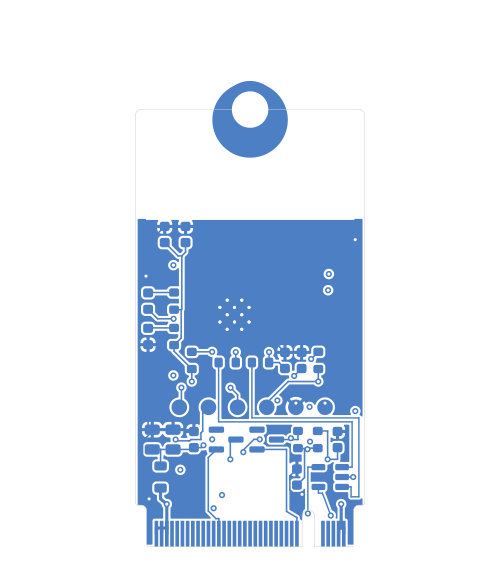
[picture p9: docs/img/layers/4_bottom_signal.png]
bottom signal


Where most of the routing lives. The gold fingers are at the bottom edge; the
3×3 dot grid under the module is the EPAD ground-via array (thermal + GND,
Espressif HDG). Thin traces threading the GND pour are the signal routes.

## How this was routed

Hand-routed + locked: the USB differential pair (impedance-critical) and the
recovery/boot nets; autorouted (freerouting, 80 passes): the header/UART/LED
signals; planes poured last. Method and the lessons behind it:
[`routing-method.md`](routing-method.md). Full source of truth for every
track/via is the KiCad PCB file — open it in the PCB Editor to explore
interactively (click a net to highlight it end-to-end).

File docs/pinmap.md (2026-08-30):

# Pin map — esp32-m2-companion (GATE 1 deliverable)

Status: **draft for owner review** · 2026-08-28

Sources (see `docs/datasheets/README.md` for provenance):
- **[MALLOW]** Mallow Carrier Board V1.1 datasheet, Table 10 (M.2 X17), Table 22 (X16), §2.5.2
- **[KEYB]** Quectel RM50xQ HW Design V1.2, Fig. 2 / Table 8 (standard WWAN Key-B socket usage)
- **[WROOM]** ESP32-S3-WROOM-1 datasheet v1.8, Table 3-1, §4
- **[HDG]** ESP32-S3 Hardware Design Guidelines (master), §power-up & reset

---

## 1. M.2 Key-B edge connector — full pin table

Notation: card edge has 75 positions; positions 12–19 are the Key-B notch
(no pins). Odd pins on top row, even on bottom row per M.2 convention.
"—" = not present in Mallow Table 10 ⇒ not connected on Mallow.

Directions ("I/O") are from the **card's** point of view.

| Pin | M.2 WWAN function [KEYB] | Mallow X17 wiring [MALLOW] | Our usage |
|----:|---|---|---|
| 1 | CONFIG_3 | NC | NC |
| 2 | VCC (3.3 V) | +V3.3_PCIE_1 | **3V3 in** |
| 3 | GND | GND | GND |
| 4 | VCC (3.3 V) | +V3.3_PCIE_1 | **3V3 in** |
| 5 | GND | GND | GND |
| 6 | FULL_CARD_POWER_OFF# | PCIE_1_CARD_PWR_OFF#, +1.8/+3.3 V, driver not documented (no SODIMM pin) | NC in v1 (see §3.4) |
| 7 | USB_DP | USBH3_D_P (USB5744 hub port 3) | **USB D+ → IO20** (via ESD array) |
| 8 | W_DISABLE1# | 47 kΩ pull-up to +V3.3_PCIE_1 only — **not SoM-driven** | **NC in v1** — exposed edge finger, no on-card connection. BOOT leg dropped (ADR 0002 amendment); recovery via TP1/TP2 (§3) |
| 9 | USB_DM | USBH3_D_N (USB5744 hub port 3) | **USB D− → IO19** (via ESD array) |
| 10 | WWAN_LED# | PCIE_1_GPIO_9 → X16 pin 15 | NC |
| 11 | GND | GND | GND |
| 12–19 | — notch — | — notch — | — notch — |
| 20 | PCM_CLK / GPIO | PCIE_1_GPIO_5 → X16 pin 19 | **BOOT# input** via Schottky diode (Mallow path; see §3) |
| 21 | CONFIG_0 | NC | NC |
| 22 | PCM_DIN / GPIO | PCIE_1_GPIO_6 → X16 pin 18 | NC (spare sideband) |
| 23 | WAKE_ON_WAN# / GPIO | PCIE_1_GPIO_11 → X16 pin 13 | NC |
| 24 | PCM_DOUT / GPIO | PCIE_1_GPIO_7 → X16 pin 17 | NC (spare sideband) |
| 25 | DPR | NC | NC |
| 26 | W_DISABLE2# | PCIE_1_GPIO_10 → X16 pin 14 | NC |
| 27 | GND | GND | GND |
| 28 | PCM_SYNC / GPIO | PCIE_1_GPIO_8 → X16 pin 16 | NC |
| 29 | USB_SS_TX_M | USBH3_SSRX_N ¹ | NC |
| 30 | UIM1_RST | PCIE_1_UIM_RESET | NC |
| 31 | USB_SS_TX_P | USBH3_SSRX_P ¹ | NC |
| 32 | UIM1_CLK | PCIE_1_UIM_CLK | NC |
| 33 | GND | GND | GND |
| 34 | UIM1_DATA | PCIE_1_UIM_DATA | NC |
| 35 | USB_SS_RX_M | USBH3_SSTX_N ¹ | NC |
| 36 | UIM1_VDD | PCIE_1_UIM_PWR | NC |
| 37 | USB_SS_RX_P | USBH3_SSTX_P ¹ | NC |
| 38 | SDX2AP_STATUS | NC | NC |
| 39 | GND | GND | GND |
| 40 | (U)SIM2 / GPIO | PCIE_1_GPIO_0 → X16 pin 24 | NC |
| 41 | PCIE_TX_M ² | PCIE_1_L0_RX_N ² | NC |
| 42 | (U)SIM2 / GPIO | PCIE_1_GPIO_1 → X16 pin 23 | NC |
| 43 | PCIE_TX_P ² | PCIE_1_L0_RX_P ² | NC |
| 44 | (U)SIM2 / GPIO | PCIE_1_GPIO_2 → X16 pin 22 | NC |
| 45 | GND | GND | GND |
| 46 | (U)SIM2 / GPIO | PCIE_1_GPIO_3 → X16 pin 21 | NC |
| 47 | PCIE_RX_M ² | PCIE_1_L0_TX_N ² | NC |
| 48 | (U)SIM2 / GPIO | PCIE_1_GPIO_4 → X16 pin 20 | NC |
| 49 | PCIE_RX_P ² | PCIE_1_L0_TX_P ² | NC |
| 50 | PERST# (PCIE_RST_N) | PERST#, **SODIMM 244**, input to card, OD, 10 kΩ pull-up to +V3.3_PCIE_1 | **EN (reset) input** via Schottky diode (see §3) |
| 51 | GND | GND | GND |
| 52 | PCIE_CLKREQ_N | NC | NC |
| 53 | PCIE_REFCLK_M | PCIE_1_CLK_N | NC |
| 54 | PCIE_WAKE_N | PCIE_1_WAKE#, SODIMM 252, 10 kΩ PU to +V1.8 | NC (1.8 V domain — do not touch) |
| 55 | PCIE_REFCLK_P | PCIE_1_CLK_P | NC |
| 56 | RFFE_CLK | NC | NC |
| 57 | GND | GND | GND |
| 58 | RFFE_DATA | NC | NC |
| 59 | LAA_TX_EN / ANT | NC | NC |
| 60 | WLAN_TX_EN | NC | NC |
| 61 | ANTCTL1 | NC | NC |
| 62 | COEX_RXD | NC | NC |
| 63 | ANTCTL2 | NC | NC |
| 64 | COEX_TXD | NC | NC |
| 65 | RFFE_VIO_1V8 | NC | NC |
| 66 | UIM1_DET | PCIE_1_UIM_CD | NC |
| 67 | RESET# | M.2_CARD_RESET#, **+1.8 V domain**, driver not documented (no SODIMM pin) | NC in v1 (see §3.4) |
| 68 | AP2SDX_STATUS | NC | NC |
| 69 | CONFIG_1 | NC | NC |
| 70 | VCC (3.3 V) | +V3.3_PCIE_1 | **3V3 in** |
| 71 | GND | GND | GND |
| 72 | VCC (3.3 V) | +V3.3_PCIE_1 | **3V3 in** |
| 73 | GND | GND | GND |
| 74 | VCC (3.3 V) | +V3.3_PCIE_1 | **3V3 in** |
| 75 | CONFIG_2 | not listed in Mallow Table 10 | NC |

¹ Naming is host-referenced on Mallow, card-referenced in [KEYB]; TX/RX pair
directions are consistent between the two once that is accounted for.
² Same host/card naming inversion for the PCIe lane.

Power notes:
- +V3.3_PCIE_1: Mallow's 3V3 DC-DC is rated 7 A board-total (Table 4) —
  ESP32-S3 WiFi TX bursts (~0.5 A) are comfortably inside slot budget.
- Card power = 5 × VCC pins, 11 × GND fingers. Input filter per SPEC §6.2.
- Note [KEYB] modem VCC is 3.135–4.4 V (modem-specific); the *socket* rail on
  both our hosts is 3.3 V, which is what we design to.

## 2. ESP32-S3-WROOM-1 pin allocation

Module: **ESP32-S3-WROOM-1-N8R2** (LCSC C2913204, in stock ~9.8 k on
2026-08-28). Quad-SPI PSRAM ⇒ IO35–37 are *available* on N8R2, but they stay
**unused** so the N16R8 (octal, IO35–37 reserved) fallback stays drop-in
compatible [WROOM Table 1-1, note b].

| Mod. pin | Name | Chip fn (default) [WROOM] | Our usage | Notes |
|---:|---|---|---|---|
| 1 | GND | — | GND | |
| 2 | 3V3 | — | 3V3 rail | 2×22 µF bulk + 100 nF/pin per [HDG] |
| 3 | EN | CHIP_PU | **Reset**: 10 kΩ PU to 3V3 + 1 µF to GND (RC per [HDG] §1.3.3), Schottky from M.2 pin 50, test point | Do not float; VIL_nRST = 0.25·VDD |
| 4 | IO4 | GPIO4/ADC1_CH3 | spare (test point optional) | |
| 5 | IO5 | GPIO5 | spare | |
| 6 | IO6 | GPIO6 | spare | |
| 7 | IO7 | GPIO7 | spare | |
| 8 | IO15 | GPIO15/XTAL_32K_P | spare | |
| 9 | IO16 | GPIO16/XTAL_32K_N | spare | |
| 10 | IO17 | GPIO17/U1TXD | spare | |
| 11 | IO18 | GPIO18/U1RXD | spare | |
| 12 | IO8 | GPIO8 | **Header: I2C SDA** | opt. pull-up footprint, DNP |
| 13 | IO19 | **USB_D−** | **M.2 pin 9** via USBLC6 | native USB-Serial-JTAG |
| 14 | IO20 | **USB_D+** | **M.2 pin 7** via USBLC6 | native USB-Serial-JTAG |
| 15 | IO3 | GPIO3, strapping (JTAG src) | NC | leave floating [WROOM §4] |
| 16 | IO46 | GPIO46, strapping (boot/ROM log) | NC | weak PD default = SPI boot ✔ |
| 17 | IO9 | GPIO9 | **Header: I2C SCL** | opt. pull-up footprint, DNP |
| 18 | IO10 | GPIO10/FSPICS0 | **Header: GPIO / SPI CS** | native FSPI set |
| 19 | IO11 | GPIO11/FSPID | **Header: GPIO / SPI MOSI** | |
| 20 | IO12 | GPIO12/FSPICLK | **Header: GPIO / SPI CLK** | |
| 21 | IO13 | GPIO13/FSPIQ | **Header: GPIO / SPI MISO** | |
| 22 | IO14 | GPIO14/FSPIWP | **Header: GPIO** | |
| 23 | IO21 | GPIO21 | **Header: GPIO** | RTC-capable |
| 24 | IO47 | GPIO47 | spare | |
| 25 | IO48 | GPIO48 | **Status LED** (active-low, side-view red at left card edge, ADR 0003) | devkit precedent for RGB on IO48 |
| 26 | IO45 | GPIO45, strapping (VDD_SPI) | NC | weak PD default = 3.3 V flash ✔ |
| 27 | IO0 | GPIO0, strapping (boot) | **BOOT#**: 10 kΩ PU to 3V3, Schottky diode from M.2 pin 20, test point TP2 | weak PU default = SPI boot |
| 28 | IO35 | GPIO35 (octal-PSRAM res.) | NC | variant compat |
| 29 | IO36 | GPIO36 (octal-PSRAM res.) | NC | variant compat |
| 30 | IO37 | GPIO37 (octal-PSRAM res.) | NC | variant compat |
| 31 | IO38 | GPIO38 | spare | |
| 32 | IO39 | GPIO39/MTCK | spare (JTAG) | |
| 33 | IO40 | GPIO40/MTDO | spare (JTAG) | |
| 34 | IO41 | GPIO41/MTDI | spare (JTAG) | |
| 35 | IO42 | GPIO42/MTMS | spare (JTAG) | |
| 36 | RXD0 | GPIO44/U0RXD | **Header: UART RX** | ROM boot log lands here too |
| 37 | TXD0 | GPIO43/U0TXD | **Header: UART TX** | |
| 38 | IO2 | GPIO2 | spare | |
| 39 | IO1 | GPIO1 | spare | |
| 40 | GND | — | GND | |
| 41 | EPAD | — | GND, ≥9 vias [HDG] | |

### IO header (12 pins, 2.54 mm, unpopulated)

`3V3 · GND · IO8/SDA · IO9/SCL · IO43/TX · IO44/RX · IO10/CS · IO11/MOSI · IO12/CLK · IO13/MISO · IO14 · IO21`

- Full native (IOMUX) FSPI set among header GPIOs (IO10–13) → SPEC G3 ✔.
- No strapping pins, no octal-PSRAM pins, no USB pins on the header.
- UART on header = UART0: doubles as fallback ROM-bootloader/console path.

## 3. Recovery scheme (SPEC §6.4)

### 3.1 Chosen sideband mapping

| Card signal | M.2 pin | Why |
|---|---|---|
| **EN** | 50 (PERST#) | Only sideband Mallow wires to a SoM pin out of the box (SODIMM 244, OD + 10 k→3.3 V on carrier). Semantically "card reset" on every host family. |
| **BOOT (GPIO0)** | 20 (Mallow: X16.19 jumper) | pin 20 via the X16 jumper covers Mallow. The pin-8 (W_DISABLE#) diode-OR leg was **dropped in v1** (ADR 0002 amendment): unroutable in the dense pin 7/8/9 corner and redundant — BOOT is on TP2, so non-Mallow hosts recover by flying-lead on TP1(EN)+TP2(BOOT). |

### 3.2 Level-domain problem and the diode solution

Verdin GPIOs are **1.8 V** and not 3.3 V-tolerant; our EN/BOOT nets are pulled
to 3.3 V. Also, an unknown host may drive sidebands push-pull at 1.8 V.
Therefore every sideband input goes through a small-signal Schottky
(anode = card net, cathode = M.2 pin):

- Host (any voltage, push-pull or OD) pulls low → card net ≈ V_OL + V_f
  ≤ ~0.5 V < VIL (0.825 V @3.3 V) ✔
- Host Hi-Z or open-drain released → diode blocks, card net sits at 3.3 V via
  its own 10 kΩ, host pin never sees 3.3 V ✔
- **Constraint (GATE 2 review finding):** a host driving a sideband
  *push-pull HIGH below ~2.8 V* (e.g. 1.8 V) forward-biases the diode
  (~125 µA) and drags the card net to ~2.0–2.1 V — inside the undefined
  input band. Host sidebands must idle open-drain/Hi-Z, or push-pull with
  V_OH ≥ ~2.8 V. Recovery flows must *release* BOOT/EN to input/Hi-Z
  (`gpioset` back to input), never drive them high. Mallow's documented
  paths satisfy this (PERST# is OD; pin 20 is open until jumpered).
- Card unplugged / sideband unconnected → normal boot ✔ (SPEC §6.4 satisfied)

Trade-off: host can only assert (pull low), never drive high — which is all
the recovery flow needs. With 10 kΩ pull-ups, diode forward current ≈ 0.3 mA
⇒ V_f ≈ 0.2–0.3 V (BAT54-class).

EN keeps the [HDG] RC (10 kΩ + 1 µF); a host reset pulse of ≥ a few ms
discharges the 1 µF through the diode — trivial with `gpioset`.

### 3.3 Resulting flows

- **Normal flash**: `esptool.py` auto-reset over USB-Serial-JTAG. No GPIO.
- **Brick recovery (Mallow)**: jumper X16.19 → chosen Verdin GPIO (one-time
  bench setup). Then: hold BOOT low (that GPIO), pulse PERST# (SODIMM 244)
  low ≥ 5 ms, release → ROM `Joint Download Boot` [WROOM Table 4-3] →
  `esptool.py` over the same USB port → flash → release BOOT.
- **Brick recovery (RPi5/Waveshare HAT)**: sideband wiring unpublished;
  best-effort per SPEC. If the HAT drives nothing, recovery needs a flying
  lead to the card's EN/BOOT test points — which is why both get test points.

### 3.4 Rejected candidates (documented per SPEC §6.4)

- **Pin 67 RESET#**: 1.8 V domain on Mallow and no documented driver — can't
  rely on it. Left NC (safe: our nets don't touch it).
- **Pin 6 FULL_CARD_POWER_OFF#**: no documented driver on Mallow; standard
  meaning is "power the card off", which modems implement in the PMIC — we
  have no power switch in v1 (SPEC: no regulator). Left NC.

## 4. USB detail

- M.2 7/9 → USBLC6-2 array (close to edge fingers) → IO20/IO19.
  90 Ω diff pair, length-matched, solid L2 GND reference, no stubs.
- Polarity: pin 7 = D+ = IO20, pin 9 = D− = IO19 [MALLOW T.10, WROOM T.3-1].
- On Mallow the port is behind a USB5744 hub (port 3) — enumeration
  expectation in `docs/bringup.md` should mention the hub in `lsusb -t`.

## 5. GATE 1 outcomes (2026-08-28)

1. BOOT: pin 20 only (Mallow). Pin-8 diode-OR leg **dropped in v1** → ADR 0002 amendment (2026-08-30); recovery on other hosts via TP1/TP2.
2. Status LED: **plain LED on IO48** → ADR 0003.
3. SODIMM 244 as GPIO: **verified in mainline device trees** for Verdin
   iMX8MP/iMX8MM (claimed by PCIe node — free it with an overlay) and AM62
   (free by default). Per-SoM table in ADR 0002; exact steps for the owner's
   SoM go into `docs/bringup.md` (Phase 4).
4. RPi5: **demoted to nice-to-have** → ADR 0004 (risk R4 accepted).

Still open (not blocking Phase 1):
- ST vs UMW for the USB ESD array — decide at BOM review (Phase 1 / GATE 2);
  if ST, owner drops the ST PDF into `docs/datasheets/`.
- M.2 2242 mechanical outline source for Phase 2 (licensed M.2 EM spec or
  verified derived drawing) — needed before GATE 3, not before schematic.

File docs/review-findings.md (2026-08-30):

# Review findings log (append-only — SPEC §12)

Format: `date · phase · severity · classification (BLOCK <name> / PROCESS / PROJECT) · finding · action`.
External-reviewer categorizations ("wrong" / "works but unprofessional" /
"fragile at scale") are preserved verbatim.

---

- 2026-08-28 · Phase 0 · medium · **PROJECT** · SPEC §6.4 sideband candidate
  list (RESET#/W_DISABLE#/FULL_CARD_POWER_OFF#) did not survive datasheet
  contact: only PERST# (pin 50) is SoM-wired on Mallow; W_DISABLE1# is
  pull-up-only; pins 6/67 have no documented driver, 67 is 1.8 V. → Mapping
  changed at GATE 1 (ADR 0002); noted in CLAUDE.md.
- 2026-08-28 · Phase 0 · medium · **BLOCK m2_keyb_edge** (self-caught) ·
  Host sideband GPIO domains vary (Verdin 1.8 V, not 3.3 V-tolerant); direct
  wiring of card 3.3 V pull-up nets to sideband pins would overvoltage 1.8 V
  hosts. → Schottky-diode isolation on every sideband input (ADR 0002);
  lesson recorded in block LESSONS.md.
- 2026-08-28 · GATE 2 · low · **PROJECT** (owner decision) · USB ESD array
  sourcing: ST USBLC6-2SC6 (C7519) primary, UMW clone (C2687116) approved
  second source. → BOM field `LCSC_2nd_source` added in usb_esd block.

## GATE 2 multi-agent adversarial review (2026-08-28, workflow wf_7e010569)

7 independent reviewers re-derived each block from source datasheets; every
finding attacked by 2 refutation verifiers (datasheet-evidence + circuit-
behavior lenses, xhigh effort). Core electrical design confirmed correct:
module pinout (0 findings), USB path polarity/pairing, recovery diode
topology & margins (≥145 mV worst-case), power budget (3.06 V worst case vs
3.0 V min). Confirmed findings:

- 2026-08-28 · GATE 2 · medium · **BLOCK sideband_recovery** · CONFIRMED (2/2
  uphold) · "Diode blocks when host high" claim false for push-pull-high
  hosts below ~2.8 V: net dragged to ~2.0–2.1 V (undefined input band),
  ~125 µA into host pin. Mallow paths unaffected (OD / open). → Docs
  corrected (pinmap §3.2, block docstring, ADR 0002 amendment); constraint
  stated; recovery flow = release to Hi-Z. LESSONS.md updated.
- 2026-08-28 · GATE 2 · low (verifiers downgraded from medium) · **BLOCK
  power_3v3 / esp32s3_companion** · CONFIRMED · BOM label "10uF 25V" wrong:
  C19702 (CL10A106KP8NNNC) is a 10 V part. Electrically fine at 3.3 V.
  → Relabeled "10uF 10V". Related: C15849 labeled 25 V is actually 50 V →
  relabeled "1uF 50V".
- 2026-08-28 · GATE 2 · low · **PROJECT** (docs) · CONFIRMED · pinmap [KEYB]
  column misquotes on NC pins: 41/43/47/49 (PCIe pair names transposed),
  38/68 (SDX2AP/AP2SDX shift), 56/58/60/64 (RFFE/WLAN/COEX names), and
  "12 × GND fingers" (actual 11). → All corrected in pinmap + _PINS.
- 2026-08-28 · GATE 2 · low · **PROCESS** (tooling) · DNP parts leaked into
  JLC assembly CSV: gen_bom keyed on a field the header block never set.
  → gen_bom now derives DNP from `do_not_populate`. Candidate rule for the
  shared hardware-design skill: "DNP handling must be enforced by the BOM
  generator, not by per-part convention."
- 2026-08-28 · GATE 2 · low · **BLOCK usb_esd** · HDG §1.3.13 series-R/
  shunt-C provision missing on USB D+/D−. → Added R7/R8 (0R populated,
  22–33R swappable) + C8/C9 (DNP), placed near module.
- 2026-08-28 · GATE 2 · low · **PROJECT** (risk) · Host-behavior failure
  modes undocumented: W_DISABLE1# low at boot ⇒ download mode (→ R10);
  stock Mallow PCIe driver may hold PERST# asserted (→ R9, verify at
  bring-up).
- 2026-08-28 · GATE 2 · low · **BLOCK power_3v3** · Rail margin is real but
  thin (~60 mV over module 3.0 V min worst-case); bead choice confirmed
  sound; recorded in LESSONS.md with "do not substitute higher-DCR bead".
- 2026-08-28 · Phase 2 · medium · **PROJECT** (self-caught) · Card exceeds
  the M.2 top-side height envelope (module 3.1 mm vs 1.5 mm): fine in open
  slots (Mallow), impossible in enclosed hosts. → risks.md R11, README note.
- 2026-08-28 · Phase 2 · medium · **PROJECT** (owner decision, ADR 0005) ·
  1×12 2.54 mm header cannot fit the 2242 card; replaced by JST SH-4
  (Qwiic) + SH-8, assembled. SPEC §6.6 amended.
- 2026-08-29 · Phase 2 · low · **PROCESS** (owner feedback) · netlistsvg
  renders have label/wire collisions (third-party layouter, not KiCad) —
  insufficient for review. → ADR 0001 fallback activated: tools/gen_sch.py
  generates a true .kicad_sch (global-label style, no crossing wires) with
  title block (project, git rev, license, credits); `make sch`. Candidate
  rule for the shared hardware-design skill: "schematic-as-code flows need a
  KiCad-native render path from day one."
- 2026-08-29 · Phase 2 · **high** · **BLOCK m2_keyb_edge** (OWNER-caught from
  3D render) · U1/C4/FB1 (bottom) and J3/J4 (top) courtyards intruded into
  the M.2 socket coverage zone: the mated connector overlaps the card's
  first ~4.8 mm on BOTH faces (EM spec Figs 38/39: 9.10 mm depth incl land
  pattern, 4.30 mm beyond card edge) — the card would not have seated.
  → All placements moved behind y=−4.8; the edge footprint now carries
  F/B.CrtYd rectangles over the zone so DRC catches this class forever.
  LESSONS.md updated. PROCESS candidate: "connector footprints must model
  the MATED envelope as courtyard, not just their own copper."
- 2026-08-29 · Phase 2 · medium · **BLOCK leds** (OWNER-caught) · Top-emitting
  LEDs invisible in-slot: card top faces away from host, bottom faces host
  at ~2.5 mm; a prior layout note claiming "bottom faces up on Mallow" was
  wrong (EM spec stack-ups: module component side faces away from host PCB).
  → Side-view LEDs at the left card edge (ADR 0003 amendment); layout-notes
  corrected; PROCESS candidate: "indicator LEDs on mezzanine cards must be
  edge-emitting or light-piped — check the mated orientation, not the bench
  view."
- 2026-08-30 · Phase 2 · high · **PROCESS** (self-caught, owner-flagged) ·
  Board routing burned ~28 full autorouter runs over a night by re-invoking
  freerouting to chase each DRC violation — every run is ~12 min AND
  reshuffles all auto-routed nets, so each fix invalidated the last. Root
  causes: (a) global-autorouter-in-the-loop instead of route-hard-nets-once-
  then-finish-by-hand; (b) guessing track coordinates instead of reading pad
  extents; (c) Python str.replace() edits silently no-matching as the file
  drifted; (d) autorouter slotting the GND/+3V3 plane layers; (e) over-strict
  skew assert on a USB-FS pair. → Full method captured in
  docs/routing-method.md. **Candidate rule for the shared hardware-design
  skill: "Never loop a global autorouter to fix individual DRC violations.
  Hand-route + lock the congested/critical nets once, autoroute the easy
  nets once, finish leftovers by hand without re-autorouting; the per-fix
  loop must be seconds (edit→DRC), not minutes."**
- 2026-08-30 · Phase 2 · medium · **BLOCK sideband_recovery** (owner
  decision) · M.2 pin-8 (W_DISABLE1_n) BOOT diode-OR leg DROPPED in v1:
  unroutable in the dense pin 7/8/9 interleave AND redundant with the
  TP1(EN)+TP2(BOOT) flying-lead recovery path. D2 pin 2 → NC; edge finger
  exposed/unconnected. Recovery preserved via host GPIO (Mallow pin 50+20)
  and test points (universal). → ADR 0002 amendment; block source +
  LESSONS.md updated; pinmap/datasheet regenerated.

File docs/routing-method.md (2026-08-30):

# Routing method — hard-won, do NOT repeat the rabbit hole

The v1 board's routing cost ~28 full autorouter runs over a night because of
a bad method, not a hard board. This document is the method to use from the
start next time (RP2350 sibling, any revision). It is a candidate rule for
the shared hardware-design skill (SPEC §12 PROCESS).

## The one-line lesson

**Route the hard/critical nets by hand ONCE and lock them; run the
autorouter ONCE for the easy nets; finish leftovers by hand WITHOUT
re-running the autorouter.** Never loop the global autorouter to chase
individual DRC violations.

## Why the rabbit hole happened

1. **Re-running freerouting for every fix.** Each run is ~12 min AND
   reshuffles all auto-routed nets, so it invalidated the previous hand-fix
   and created new collisions elsewhere. 28 × 12 min ≈ one wasted night.
   The per-fix feedback loop must be **seconds** (edit tracks → DRC), which
   means *not* re-invoking the autorouter.
2. **Guessing coordinates blind** instead of reading actual pad extents.
   A pad is 1.475 mm wide; "x99.0" looked between two parts but was *inside*
   a pad. Always read `pad.GetPosition()`/`GetSize()` and compute the real
   gap before placing a track.
3. **Silent edit drift.** Python `str.replace()` no-ops when the text has
   moved, so "fixes" silently didn't apply and I re-fixed non-problems. Use
   an editor that ERRORS on mismatch, or `assert old in text`, every time.
4. **Letting the autorouter use the plane layers.** freerouting treated
   In1(GND)/In2(+3V3) as signal layers and slotted them, leaving gaps.
5. **Over-constraining.** A 2 mm intra-pair skew assert fired on a USB-**FS**
   pair where 10 mm (≈67 ps) is invisible. Match effort to the signal.

## The efficient method (use this order)

### 0. Estimate congestion BEFORE choosing a method
- Card usable width minus the dominant component footprint = routing budget.
  Here: 22 mm card − 18 mm module ≈ 2 mm side strips + the module underside.
  That density means **plan for interactive routing of the dense corner from
  the start** — don't expect any autorouter to nail it.

### 1. Hand-route + LOCK the critical and congested nets, once
- USB/diff pairs, recovery straps, power entry, anything in a pinch point.
- Read pad coordinates from the board; compute gaps; place tracks; lock them
  (`track.SetLocked(True)`).
- For diff pairs: prioritise impedance continuity + solid reference, not
  length-matching, for FS/LS USB.

### 2. Run the autorouter ONCE, for the easy nets only
- Mark plane layers as power in the DSN so the autorouter can't slot them
  — BUT verify it can still route the remaining signals on 2 layers; if the
  board needs inner-layer routing, leave them signal and accept it. (On this
  board, forbidding inner layers left 67 nets unroutable — so here the inner
  layers ARE needed, i.e. it is not a clean SIG/GND/PWR/SIG board.)
- Use few passes (`-mp 5`) for "routed, not optimal"; high passes only for a
  final polish.
- Pre-routed locked tracks are exported as `(type fix)` and are respected.

### 3. Stitch power deterministically, don't rely on the autorouter
- Every SMD pad on a plane-only net (e.g. +3V3 on In2 with no outer pour)
  needs its OWN via to the plane. But place vias where they DON'T collide:
  check neighbouring pad extents; do NOT blindly offset a fixed distance
  (that shorted EN/USB pads here). Prefer via-in-pad on the pad itself
  (same net → no clearance issue; JLC fills it).

### 4. Finish leftovers by hand, NO autorouter re-run
- Load the routed board, add the few missing connections as locked tracks,
  re-pour, DRC. Iterate this in **seconds**. This is where convergence
  actually happens.

### 5. The genuinely impossible corner → interactive GUI
- A 0.5 mm-pitch, 3-conductor interleave where 2 conductors need
  layer-change vias (vias 0.6 mm > 0.5 mm pitch) cannot be placed blindly.
  On this board that was M.2 pins 7/8/9 (USB D+/W_DISABLE/USB D−). Route it
  in pcbnew interactively (fan the pair's vias apart a few mm south first),
  or accept it as an owner GUI task. Do NOT script-iterate it.

## Tooling notes (this repo)

- `hardware/tools/route.py`: `preroute_usb` + `preroute_fixups`/`more_fixups`
  (hand-routed locked tracks), `run_freerouting` (once), `pour_planes`.
- Regenerate placement: `tools/gen_pcb.py` (rebuilds board from netlist —
  **destroys routing**; only for pre-route placement changes).
- Once routing starts, switch to KiCad "Update PCB from netlist" for
  schematic tweaks so tracks survive.
- DRC headless: `kicad-cli pcb drc --severity-error ...`.
- Ratsnest count (real unrouted): `board.GetConnectivity().GetUnconnectedCount(True)`.
- Known-benign DRC on this board: 3 J1 footprint-internal artifacts
  (mounting-pad/keepout/silk polygons on the edge connector).

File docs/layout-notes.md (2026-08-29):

# Phase 2 layout notes — esp32_m2_companion.kicad_pcb

Generated by `hardware/tools/gen_pcb.py` (rerun after any netlist change —
it rebuilds the board from scratch; your routing lives in the same file, so
after you start routing we switch to KiCad's *Update PCB from netlist*
instead of regenerating. Tell me when you start.)

Open `hardware/kicad/esp32_m2_companion.kicad_pcb` (project file + custom
DRC rules alongside).

## What's already set

- 4 layers (SIG/GND/PWR/SIG per SPEC), 0.8 mm, outline+fingers from the
  spec-verified `M2_KeyB_2242_EdgeFingers` footprint (J1 at board origin).
- DRC: JLCPCB minima (0.127 mm track/clearance, 0.3 mm drill, 0.45 mm via);
  edge-clearance waived for J1 only (`.kicad_dru`); intra-footprint mask
  bridges allowed (0.5 mm finger pitch merges apertures — standard).
- Netclass `USB_DIFF` on all USB nets. **Width/gap are placeholders
  (0.15/0.15): run JLCPCB's impedance calculator for the 0.8 mm 4-layer
  stackup (JLC04081H) and set the real 90 Ω geometry before routing.**
- Antenna keep-out rule area (all copper layers), y −37.6..−31.4 card coords.

## Placement rationale (adjust freely)

- Module top edge 4.5 mm below card top: the M.2 screw head owns the
  top-center (Ø~6 zone; the J1 footprint carries its own keep-out there).
- USBLC6 (U1) near fingers 7/9; diff pair runs up the right side to module
  pins 13/14 through bottom-side R7/R8 (0R series, HDG provision) — route
  edge→U1→(via)→R7/R8→module, referenced to L2 GND, no stubs.
- Bottom side (faces the CARRIER underside at ~2.5 mm in the Mallow slot —
  the card top faces away from the host PCB, i.e. downward on Mallow):
  test points TP1–TP6, USB series/shunt provision, module 3V3 decoupling
  (C6/C7) + EN RC (C5/R1) under module pins 1–3.
- Power entry FB1 near VCC fingers (left); bulk row behind it.

## Known-open items

1. ~~J3 header~~ **Resolved (ADR 0005)**: JST SH-4 Qwiic (J3) + SH-8 (J4),
   assembled, top side. Their courtyards consume the whole lower top zone,
   which forced item 2:
2. **Top/bottom split is now: top = module + connectors; bottom = all
   passives + USBLC6 + diodes + LEDs + TPs.** The owner's "no bottom
   components" wish is geometrically incompatible with two top-side
   connectors — the two constraints cannot both hold on 22 mm width.
   Consequence: two-sided assembly (or ~15 min hand-soldering) — GATE 4.
   LEDs are SIDE-VIEW parts at the left card edge (ADR 0003 amendment):
   they emit out of the slot gap and are visible in any orientation.
3. Residual DRC: ~12 courtyard-overlap infos (sub-0.4 mm kisses, fine-tune
   while routing) + 3 J1-internal artifacts (footprint's own mounting pad
   inside its own screw keep-out — benign). No shorts, no clearance errors.
4. Bevel/panel decision (risks R2): JLCPCB bevel is 30° and needs ≥50×50 mm
   panels with fingers on the panel edge — or skip bevel for v1.
5. USB 90 Ω geometry: run JLCPCB's impedance calculator for the 0.8 mm
   4-layer stackup and update the USB_DIFF netclass before routing.

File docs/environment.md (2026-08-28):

# Environment log

Machine: Stefano's Mac (Darwin 25.5.0, zsh) — note: SPEC §8 mentions server
`m920x`; this session actually runs on macOS. Flag if tooling must live on
m920x instead.

| Date | Tool / package | How | Why |
|---|---|---|---|
| 2026-08-28 | python3 3.9.6 + pypdf | pre-existing | datasheet text extraction |
| 2026-08-28 | `cryptography` (pip3 --user) | `pip3 install --user cryptography` | pypdf AES support (Quectel PDF is encrypted) |
| 2026-08-28 | poppler (pdftoppm/pdftotext) | `brew install poppler` | render PDF pages for visual inspection of mechanical drawings |

Network notes (this machine/sandbox):
- `st.com` and `mouser.com` downloads blocked → USBLC6 datasheet fetched from
  a mirror (UMW clone doc); see docs/datasheets/README.md.
- Waveshare wiki reachable via curl with browser UA (plain fetch gets 403).

| 2026-08-28 | uv 0.9.x | `brew install uv` | python project/venv management |
| 2026-08-28 | KiCad 9.0.9 (kicad-cli + libs) | official DMG → `~/Applications/KiCad` (brew cask needs sudo → hand-install; SPEC pins v9, brew only has v10) | headless ERC/DRC/exports, symbol/footprint libs |
| 2026-08-28 | atopile 0.15.8 | `uv tool install atopile` | evaluated & REJECTED (ADR 0001); kept installed for reference |
| 2026-08-28 | skidl 2.3.0 + pypdf | `uv add` in hardware/ | schematic-as-code (ADR 0001), PDF merge |
| 2026-08-28 | node 26 + graphviz (incl. rsvg-convert) | `brew install node graphviz` | netlistsvg rendering, SVG→PDF |
| 2026-08-28 | netlistsvg | `npm install -g netlistsvg` | schematic-style SVG from netlists |

Still to install (Phase 4): ESP-IDF.

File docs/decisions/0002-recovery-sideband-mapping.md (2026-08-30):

# ADR 0002 — Recovery sideband mapping & Schottky isolation

Date: 2026-08-28 · Status: **accepted** (GATE 1, owner)

## Decision

- **EN** ← M.2 pin 50 (PERST#), via small-signal Schottky (anode on card net),
  on-card 10 kΩ pull-up to 3V3 + RC (10 kΩ/1 µF) per Espressif HDG.
- **BOOT (GPIO0)** ← diode-OR of M.2 pin 20 (Mallow X16 jumper path) **and**
  pin 8 (W_DISABLE1#, for hosts that wire it), on-card 10 kΩ pull-up.
- All sideband inputs are diode-isolated so 1.8 V hosts (Verdin GPIOs are not
  3.3 V-tolerant) can pull low without ever seeing our 3.3 V pull-ups.

## Context

Mallow V1.1 wires only PERST# (pin 50 → SODIMM 244) to the SoM; W_DISABLE1#
is pull-up-only; pins 6/67 have no documented driver (67 is 1.8 V domain).
Pins routed to X16 allow jumpering BOOT to any SoM GPIO. Details and rejected
candidates: docs/pinmap.md §3.

## SODIMM 244 usability as GPIO (verified in mainline device trees)

| Verdin SoM | SoC line for SODIMM 244 | Default DT owner | To free for gpioset |
|---|---|---|---|
| iMX8M Plus | GPIO4_IO19 (SAI1_TXD7 pad) | `&pcie` `reset-gpio` (imx8mp-verdin.dtsi:800–804) | overlay disabling `&pcie` |
| iMX8M Mini | GPIO3_IO19 (SAI5_RXFS pad) | `&pcie0` `reset-gpio` (imx8mm-verdin.dtsi:706–708) | overlay disabling `&pcie0` |
| AM62 | MCU_GPIO0_0 | gpio-hog present but `status = "disabled"` (k3-am62-verdin.dtsi:1432–1438) | free by default |

iMX8MP and AM62 dtsi name the line `"SODIMM_244"`, so
`gpioset $(gpiofind SODIMM_244)=0` works without chip/line hunting.
Exact overlay steps per owner's SoM go into docs/bringup.md (Phase 4).

## Consequences

- Recovery on Mallow needs one jumper wire (X16.19 → chosen SoM GPIO) for
  BOOT; EN works with zero carrier modification.
- Hosts can only assert (pull low), never drive high — sufficient for the
  recovery flow; default state comes from on-card pull-ups.

## Amendment (2026-08-28, GATE 2 adversarial review)

The original "Consequences" overstated the isolation: the diode blocks only
when the host sideband is **Hi-Z or open-drain released**. A host driving
push-pull HIGH below ~2.8 V (e.g. 1.8 V) forward-biases the diode (~125 µA)
and drags EN/IO0 to ~2.0–2.1 V — inside the undefined input band
(VIL 0.825 V / VIH 2.475 V @ 3.3 V). Real constraint: host sidebands must
idle OD/Hi-Z or push-pull with V_OH ≥ ~2.8 V; recovery flows must RELEASE
BOOT/EN to input/Hi-Z, never drive them high. Mallow's documented paths
satisfy this. Two host-behavior failure modes recorded in docs/risks.md:
W_DISABLE1# held low at boot forces download mode (R10); a stock Mallow
image's PCIe driver may leave PERST# asserted (R9).

## Amendment (2026-08-30, owner): pin-8 (W_DISABLE1#) BOOT leg DROPPED in v1

The BOOT diode-OR originally took two inputs: M.2 pin 20 (PCIE_1_GPIO_5,
Mallow) and M.2 pin 8 (W_DISABLE1_n, generic non-Mallow hosts). The pin-8
leg is **removed for v1**. Two reasons:

1. **Redundant.** BOOT (IO0) is exposed on **TP2** and EN on **TP1**, so any
   host — Mallow or not — can force ROM download by driving TP1(EN)+TP2(BOOT)
   with flying leads (or jumping straight to the module). The Mallow in-slot
   path (pin 50 EN + pin 20 BOOT) is fully routed and unaffected. Pin 8 only
   added *automatic* BOOT on a non-Mallow host that (a) bricks, (b) can't be
   physically touched, AND (c) wires pin 8 to a controllable GPIO — a
   near-empty intersection. Note even Mallow only pulls pin 8 up through a
   resistor (not GPIO-driven), so pin 8 is non-functional there anyway.
2. **Unroutable in this placement.** Pin 8 sits in a 0.5 mm-pitch
   3-conductor interleave (USB D+/W_DISABLE/D− on M.2 pins 7/8/9) with no
   legal path to D2 on either copper layer; see docs/routing-method.md and
   review-findings.md.

Result: D2's second cathode (pin 2) is NC; the M.2 pin-8 edge finger is an
exposed but unconnected pad (kept for mechanical/standard-pinout reasons).
Recovery capability is preserved in full via host GPIO (Mallow) and
TP1/TP2 flying leads (universal). Recovery procedure: DATASHEET.md +
(Phase 4) docs/bringup.md.

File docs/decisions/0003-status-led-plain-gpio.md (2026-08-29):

# ADR 0003 — Status LED: plain LED on IO48

Date: 2026-08-28 · Status: **accepted** (GATE 1, owner)

Plain LED, active-low, series resistor, on GPIO48 (module pin 25). WS2812B-2020
option rejected for v1: extra part (Extended at JLCPCB), timing-sensitive
driver, no functional gain for a heartbeat indicator. IO48 has devkit
precedent (RGB LED on ESP32-S3-DevKitC), is not a strapping pin, and is free
on N8R2/N16R8 (the 1.8 V VDD_SPI caveat applies only to R16V variants,
WROOM-1 datasheet v1.8 Table 3-1 note c).

## Amendment (2026-08-29, owner-caught): side-view LEDs at the card edge

Top-emitting LEDs are useless on an M.2 card in-slot: the top faces away
from the host PCB (downward on Mallow, socket on carrier bottom) and the
bottom faces the host at ~2.5 mm. Replaced with side-view LEDs emitting out
of the LEFT card edge (visible in any orientation, standard on commercial
M.2 cards): D3 green TJ-S1706SW6TGLC2G-A5 (C273616), D4 red
TJ-S1706SW6TGLC2R-A5 (C273612), both Extended, 330R series (C23138 Basic).
Land pattern = 0603 placeholder — verify against the TOGIALED drawing and
emitting-face orientation on the assembly drawing at GATE 3.
An earlier note claiming "the card bottom faces up in the Mallow slot" was
WRONG and is corrected in docs/layout-notes.md.

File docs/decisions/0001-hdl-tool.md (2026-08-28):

# ADR 0001 — Schematic-as-code tool: SKiDL (atopile rejected)

Date: 2026-08-28 · Status: accepted

## Decision

**SKiDL 2.3.0** (Python, KiCad 9 toolchain) is the schematic source language.
atopile was evaluated first per SPEC §8 preference and rejected.

## Evidence against atopile (evaluated 0.15.8, 2026-08-28)

- The CLI itself warns on every run: *"atopile 0.15.8 is the last CLI release
  and is in maintenance mode only. The CLI has been replaced by the app at
  app.atopile.io (atopile 0.16+)."*
- Part picking now routes through their cloud service (`ato auth ...`).
- SPEC's fallback clause targeted "component/footprint availability"; the
  actual blocker is broader: a deprecated CLI and a SaaS dependency are
  incompatible with this project's hardware-as-code requirements (headless
  `make check`, git-only source of truth, reproducibility years from now).

## Why SKiDL fits

- Plain Python in git; blocks are functions → SPEC §12 reusable-block
  structure and the RP2350 sibling derivation (G7) map naturally.
- Native KiCad 9 support: uses the official KiCad symbol/footprint libraries
  (ESP32-S3-WROOM-1, USBLC6-2SC6, BAT54A all present), emits a KiCad netlist
  the owner imports into pcbnew for Phase 2.
- Built-in ERC, runs headless in `make check`.
- Pin assignments are made by module pin *number* with runtime asserts that
  the KiCad symbol's pin *name* matches the datasheet — traceability check
  executes on every build.

## Consequences / accepted trade-offs

- No classic schematic sheet as native output. GATE 2's "human-readable
  schematic PDF" is produced from the netlist (netlistsvg/graphviz rendering,
  one page per block); if review finds it insufficient, fallback is a
  one-time KiCad schematic derived from the netlist (kept generated, never
  hand-edited).
- KiCad 9.0.9 pinned (SPEC §8) even though KiCad 10 is current.

## Amendment (2026-08-29)

The netlistsvg render path proved insufficient at owner review (label
collisions). The fallback named above is now implemented as
`hardware/tools/gen_sch.py`: a generated KiCad 9 `.kicad_sch` (global-label
style), exported to PDF with a full title block (project, date, git rev,
CERN-OHL-P v2 license, credits). Still generated-only — never hand-edited.

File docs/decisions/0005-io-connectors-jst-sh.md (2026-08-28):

# ADR 0005 — IO header replaced by JST SH connectors (SPEC §6.6 amendment)

Date: 2026-08-28 · Status: accepted (owner)

## Context

SPEC §6.6 asked for an unpopulated 1×12 2.54 mm header "along the long card
edge". Geometry veto: 12 × 2.54 = 30.5 mm > 22 mm card width, and the strips
beside the 18 mm module are 2 mm. Owner direction: "something small, one or
two connectors with small footprints".

## Decision

Two JST SH (1.0 mm) side-entry SMT connectors, **assembled** (no longer
unpopulated — SH is not hand-solder-friendly, and cables are pre-made):

- **J3 = SM04B-SRSS-TB (LCSC C160404, Extended)** — Qwiic/STEMMA-QT pinout
  (GND, 3V3, SDA, SCL): the I2C ecosystem standard; sensors plug in with
  off-the-shelf cables.
- **J4 = SM08B-SRSS-TB (LCSC C160407, Extended)** — TX, RX, CS, MOSI, CLK,
  MISO, IO14, IO21: full native FSPI set + UART0 + two GPIO.

All 12 originally-planned signals remain exposed. I2C pull-ups stay DNP.

## Consequences

- Owner needs SH-4 (Qwiic) and SH-8 1.0 mm cable assemblies instead of
  2.54 mm jumper wires.
- Two more Extended BOM lines (justified: no Basic 1 mm connectors exist).
- In-slot cable routing is tight (side entry, 1.6 mm tall); primary IO use
  case is bench / extender / flipped carrier.

## Amendment (2026-08-28, owner): vertical entry

Side-entry (SM..) plugs cannot be mated with the card in the M.2 slot — the
socket housing blocks the ~10 mm straight approach the plug needs, so cables
would have to be attached before insertion. Switched to the **vertical
top-entry variants**: J3 = BM04B-SRSS-TB (C160390), J4 = BM08B-SRSS-TB
(C160394, 2nd source C265120 TBT reel). Plugs mate perpendicular to the
card, which works in-slot given the open space below the Mallow carrier
(card top faces down; verify finger clearance at bring-up). Footprints are
also less than half as deep (3 mm vs 6.65 mm), relaxing the lower zone.

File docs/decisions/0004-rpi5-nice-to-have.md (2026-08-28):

# ADR 0004 — RPi5 host demoted to nice-to-have

Date: 2026-08-28 · Status: **accepted** (GATE 1, owner)

SPEC §4 listed RPi5 + Waveshare Key-B HAT as secondary target; owner demoted
it to **nice-to-have** (no design decision may be blocked by it, no dedicated
hardware provisions beyond what Mallow needs). Rationale: the Waveshare
"PCIe TO 4G/5G M.2 USB3.2 HAT+" officially fits 3042/3052 only, publishes no
schematic, and its sideband wiring is unknown (docs/risks.md R4).

What survives for RPi5 compatibility at zero cost: standard Key-B pinout
usage, USB 2.0 on pins 7/9, EN/BOOT/UART0/3V3/GND test points for flying-lead
recovery, diode isolation making unknown sideband drivers safe.

SPEC success criterion 6 ("same result on RPi5") is now best-effort.

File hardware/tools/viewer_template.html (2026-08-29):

# ESP32 M.2 Companion

pre-route placement · GATE 3 pending

Form factor

M.2 Key-B 2242

Board

22 × 42 × 0.8 mm, 4 layers

MCU

ESP32-S3-WROOM-1-N8R2

Top

module + 2x JST SH (vertical)

Bottom

passives, ESD, TPs

drag rotate · scroll zoom · right-drag pan

loading board…

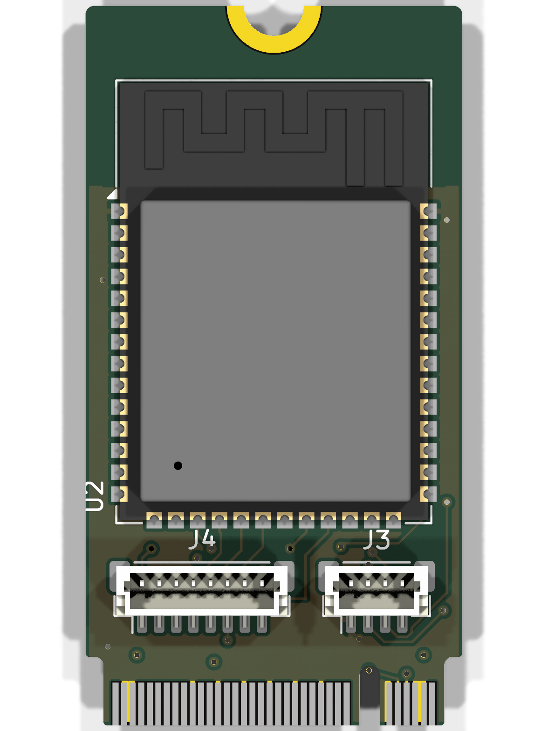
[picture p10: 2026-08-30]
docs/img/board_top.png

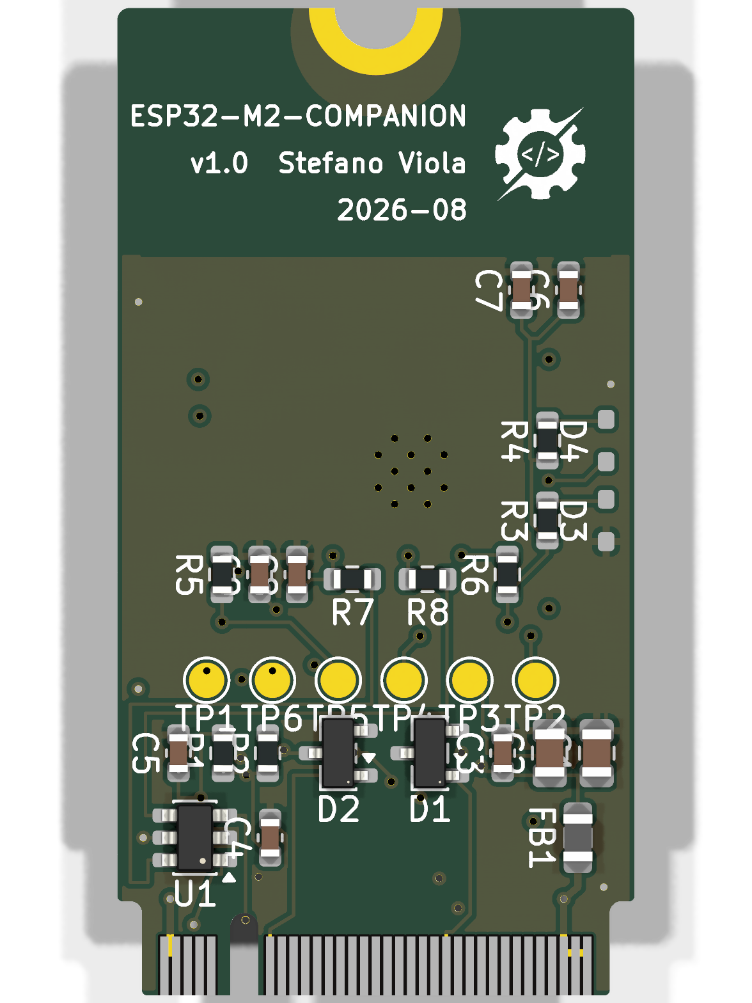
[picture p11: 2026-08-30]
docs/img/board_bottom.png

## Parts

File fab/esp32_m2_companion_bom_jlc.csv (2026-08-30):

Comment | Designator | Footprint | LCSC Part #
22uF 25V | C1,C2 | C_0805_2012Metric | C45783
10uF 10V | C3,C7 | C_0603_1608Metric | C19702
100nF 50V | C4,C6 | C_0603_1608Metric | C14663
1uF 50V | C5 | C_0603_1608Metric | C15849
BAT54A | D1,D2 | SOT-23 | C12743
green | D3 | LED_TJ-S1706_SideView | C273616
red | D4 | LED_TJ-S1706_SideView | C273612
100R@100MHz 800mA | FB1 | L_0805_2012Metric | C1015
Conn_01x04 | J3 | JST_SH_BM04B-SRSS-TB_1x04-1MP_P1.00mm_Vertical | C160390
Conn_01x08 | J4 | JST_SH_BM08B-SRSS-TB_1x08-1MP_P1.00mm_Vertical | C160394
10k | R1,R2 | R_0603_1608Metric | C25804
330R | R3,R4 | R_0603_1608Metric | C23138
0R | R7,R8 | R_0603_1608Metric | C21189
USBLC6-2SC6 | U1 | SOT-23-6 | C7519
ESP32-S3-WROOM-1 | U2 | ESP32-S3-WROOM-1_JLC | C2913204

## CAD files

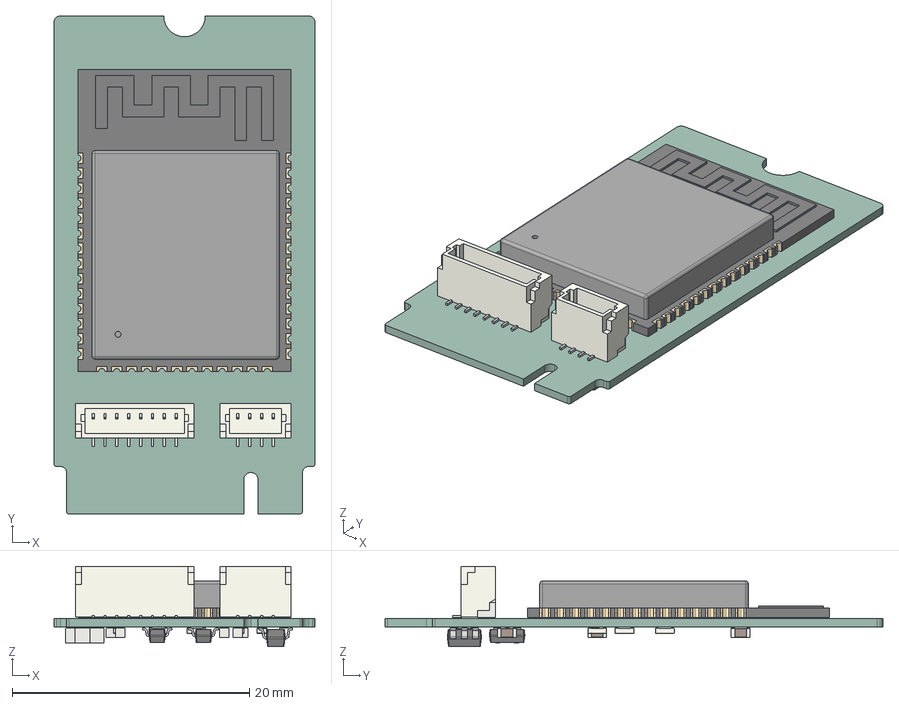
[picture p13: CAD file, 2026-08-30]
docs/3d/esp32_m2_companion.step
22.0 x 42.0 x 6.75 mm
JST_SH_BM04B-SRSS-TB_1x04-1MP_P1.00mm_Vertical
JST_SH_BM08B-SRSS-TB_1x08-1MP_P1.00mm_Vertical
ESP32-S3-WROOM-1
R_0603_1608Metric x 8
C_0603_1608Metric x 7
C_0805_2012Metric x 2
SOT-23 x 2
SOT-23-6
L_0805_2012Metric
esp32_m2_companion_PCB

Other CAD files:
docs/3d/esp32_m2_companion.stl

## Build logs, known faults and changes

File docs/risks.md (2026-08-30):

# Risk register

| ID | Risk | Status 2026-08-28 | Mitigation / next step |
|---|---|---|---|
| R1 | Mallow B-key USB wiring & sideband→SoM mapping unconfirmed | **Resolved.** USB 2.0 on pins 7/9 (via USB5744 hub port 3); PERST# (pin 50) → SODIMM 244 is the only SoM-wired sideband; W_DISABLE1# (pin 8) is pull-up-only; pins 6/67 have no documented driver; PCIE_1_GPIO_0..11 go to X16 header only (jumper wires needed for BOOT). SODIMM 244 confirmed a plain SoC GPIO on iMX8MP/iMX8MM/AM62 (ADR 0002); DT overlay needed on iMX8M* images. | Per-SoM `gpioset` steps → docs/bringup.md (Phase 4). |
| R2 | JLCPCB gold fingers + bevel on 0.8 mm 4-layer | **Mostly resolved.** Gold fingers OK on 0.8 mm (ENIG required). BUT: bevel is 30° only (SPEC said 45°) and chamfering needs ≥50×50 mm boards, not available on V-cut inner edges → single 22×42 card can't be beveled. | GATE 3/4 decision: panelize with finger edges on the panel boundary, or skip bevel for v1 (low-force socket, careful insertion). SPEC §5 wording needs owner amendment either way. |
| R3 | Antenna flat against carrier board | Accepted (v1) | Keep-out per Espressif HDG; best-effort. |
| R4 | 2242 fit in RPi5 Key-B HATs | **Accepted.** RPi5 demoted to nice-to-have at GATE 1 (ADR 0004). Waveshare HAT+ fits 3042/3052 only; no published schematic; USB 2.0 presence inferred from official SIM7600-M.2 (USB2-only modem) support. | Best-effort via test points / flying leads; no design decision may block on RPi5. |
| R5 | GPIO choice vs octal-PSRAM reservation | **Resolved by design.** IO35–37 kept NC; N8R2 ⇄ N16R8 drop-in compatible. | — |
| R6 | 1.8 V host GPIO domain (Verdin) vs 3.3 V card nets | New | Schottky-diode isolation on all sideband inputs (pinmap §3.2). |
| R7 | USBLC6 datasheet on file is the UMW clone, not ST original | **Resolved (sourcing).** Owner decision: ST C7519 primary, UMW C2687116 approved second source. | Owner to drop the ST PDF into docs/datasheets/ when convenient (st.com blocked from this machine); UMW doc on file covers the pin map either way. |
| R8 | M.2 EM spec (mechanical outline, gold-finger geometry) paywalled | **Resolved.** archive.org copy of EM Spec Rev 1.0 stored in docs/datasheets; hardware-verified open-source Key-B 2242 card footprint (CERN-OHL-P) vendored in hardware/kicad/esp32m2.pretty. | Pad-by-pad verification of footprint vs spec + pinmap before GATE 3 (see PROVENANCE.md). |
| R9 | Stock Mallow image: PCIe driver owns SODIMM 244 (PERST#); if its failed probe leaves the GPIO asserted low, the card is held in reset and never enumerates | New (GATE 2 review) | Verify at bring-up on unmodified image; document the overlay/DT fix in docs/bringup.md. Kernel-version dependent. |
| R10 | Hosts that legitimately hold W_DISABLE1# (pin 8) low from power-up force Joint Download Boot — card appears dead | **Moot in v1:** pin-8 BOOT leg removed (R10b / ADR 0002 amendment), so a host holding pin 8 low no longer affects boot. Pin 8 is now an unconnected edge finger. |
| R11 | Card violates M.2 height envelope: WROOM module is 3.1 mm tall vs 1.5 mm top-side component limit (self-caught, GATE 2 follow-up) | Accepted for v1 | Works in open slots (Mallow: X17 on carrier bottom, open air below); will NOT fit enclosed hosts (laptops) or under heatsinks. Note in README host table. |
| R10b | Pin-8 (W_DISABLE1#) auto-BOOT path removed in v1 | **Accepted (ADR 0002 amendment).** Redundant with TP1/TP2 flying-lead recovery; unroutable in this placement. | Non-Mallow bricked-card recovery uses TP1(EN)+TP2(BOOT). If a future host needs auto pin-8 BOOT, revisit placement in v2. |

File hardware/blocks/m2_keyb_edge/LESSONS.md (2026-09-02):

# LESSONS — m2_keyb_edge

- 2026-08-28: Host sideband GPIO voltage domains vary (Verdin = 1.8 V, not
  3.3 V-tolerant). Never expose card pull-up nets directly on sideband pins;
  isolate every sideband input with a Schottky diode (host can pull low,
  never sees the card rail). (ADR 0002)
- 2026-08-28: Don't trust SPEC-level assumptions about which sideband pins a
  host actually drives — read the carrier schematic/datasheet table; on
  Mallow only PERST# is SoM-wired.
- 2026-08-29: The mated M.2 socket covers the card's first ~4.8 mm on BOTH
  faces (EM spec Figs 38/39). Model it as F/B courtyard IN the edge-finger
  footprint so placement violations are DRC errors, not review luck.
  (Owner caught U1 sitting in the zone from a 3D render.)
- 2026-08-30: The M.2 edge fingers at pins 7/8/9 (USB_D+ / W_DISABLE1# /
  USB_D−) are a 0.5 mm-pitch 3-conductor interleave where the two USB nets
  need layer-change vias (0.6 mm > 0.5 mm pitch). This corner cannot be
  auto-/blind-routed; route it interactively (fan the USB via pair a few mm
  inboard first to open a lane for the middle net). Anticipate this on any
  card where the module width leaves <~2 mm side strips.
- 2026-09-02 (**$38 lesson**, caught in JLCPCB review): the M.2 mounting
  semicircle is a **plated (PTH) hole centred on the top edge** → the fab sees
  a half-cut plated hole and flags "castellated holes not selected". Choosing
  proper castellated processing cost **$38 flat** (specialty-process setup fee,
  independent of hole count) on the v1 run. But our mounting hole carries **no
  net** — it's purely mechanical — so the plating buys nothing electrical.
  **Fix for rev B (and the RP2350 sibling that reuses this edge): make the
  mounting hole NPTH (non-plated).** A bare routed notch still takes the screw,
  drops no castellation flag, and avoids the fee. Only keep it PTH if you
  actually ground the mounting hole to the standoff for shielding (we don't).
- 2026-09-02 (caught in JLCPCB production-file review, **not** by our DRC): a
  `USBH3_D_N` (host-USB) via and a redundant GND stub sit right at the B-key
  notch. The outline milling grazes the via **pad** (drilled barrel is 0.15 mm
  clear, so the via survives) and clips the GND stub (harmless plane copper).
  **Root cause:** our `esp32_m2_companion.kicad_dru` waives `edge_clearance`
  for *all* `memberOfFootprint('J1')` — added so the gold fingers can legally
  touch the edge, but it **also suppressed the legitimate copper-near-notch
  warning**. DRC passed green; JLC's independent check caught it. **Fix (rev
  B):** (1) pull that USB via ≥0.3 mm inboard of the notch; (2) delete the
  dangling GND stub; (3) tighten the dru so edge-clearance is waived only for
  the finger *pads* (condition on pad/net), never vias/tracks — so a real
  copper-in-the-mill-path error can't hide again. Proceeded on v1 (prototype,
  barrel clear, no signal net severed).

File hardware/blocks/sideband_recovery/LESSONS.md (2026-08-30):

- 2026-08-28 (GATE 2 review): diode isolation only blocks toward Hi-Z/OD
  hosts. Push-pull HIGH below ~2.8 V forward-biases the diode → card net
  ~2.0–2.1 V = undefined input. State the host-side constraint explicitly;
  recovery flows release lines to Hi-Z, never drive high.
- 2026-08-28 (GATE 2 review): W_DISABLE#-to-BOOT mapping means a host that
  asserts W_DISABLE# at power-up forces download boot. Document the
  incompatible host class; keep that diode leg DNP-able.
- 2026-08-30: Dropped the M.2 pin-8 (W_DISABLE1#) BOOT leg in v1. Lesson:
  don't rely on M.2 sideband pins for a *secondary* recovery path when the
  same signal is already on a test point — the test point + flying lead
  covers every host, while a second edge-pin leg adds routing load in the
  worst corner for near-zero real benefit. Expose EN/BOOT on test points
  and keep the sideband count minimal.

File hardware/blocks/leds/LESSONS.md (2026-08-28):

- 2026-08-28 (GATE 2 review): tooling — DNP must be a BOM-generator-visible
  field, not just a schematic attribute; J3 leaked into the JLC assembly CSV
  because only `do_not_populate` was set. gen_bom now derives DNP from it.

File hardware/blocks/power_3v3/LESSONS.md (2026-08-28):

- 2026-08-28 (GATE 2 review): worst-case rail stack-up: host 3.3 V −5% =
  3.135 V, minus FB1 DCR drop (150 mΩ × 500 mA = 75 mV) → 3.06 V at module
  vs 3.0 V min — only ~60 mV margin. Do NOT substitute a higher-DCR bead
  (e.g. 0603 with 300–600 mΩ would erase the margin). 0R link is the
  fallback if margin is ever needed.

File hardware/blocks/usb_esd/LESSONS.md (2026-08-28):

- 2026-08-28 (GATE 2 review): Espressif HDG §1.3.13 wants reserved series-R
  (22/33 R start) + shunt-C footprints near the chip on USB D+/D-. Added as
  0R populated + DNP caps. Cheap respin insurance, especially with a
  gold-finger transition in the path.

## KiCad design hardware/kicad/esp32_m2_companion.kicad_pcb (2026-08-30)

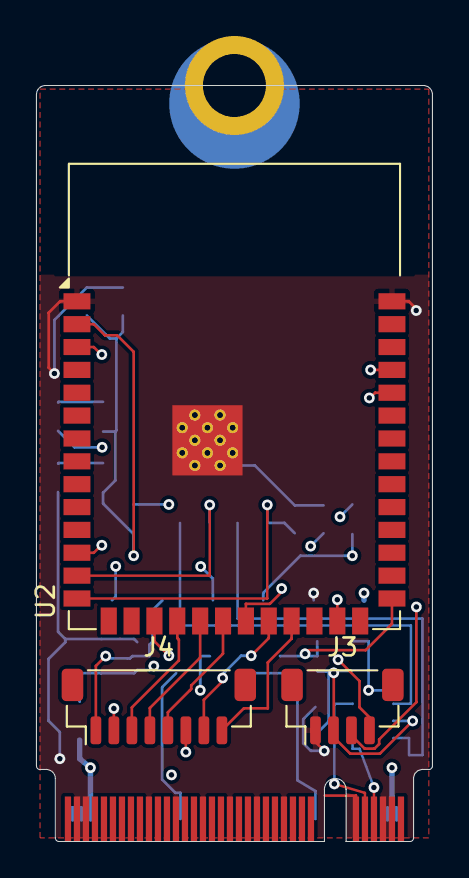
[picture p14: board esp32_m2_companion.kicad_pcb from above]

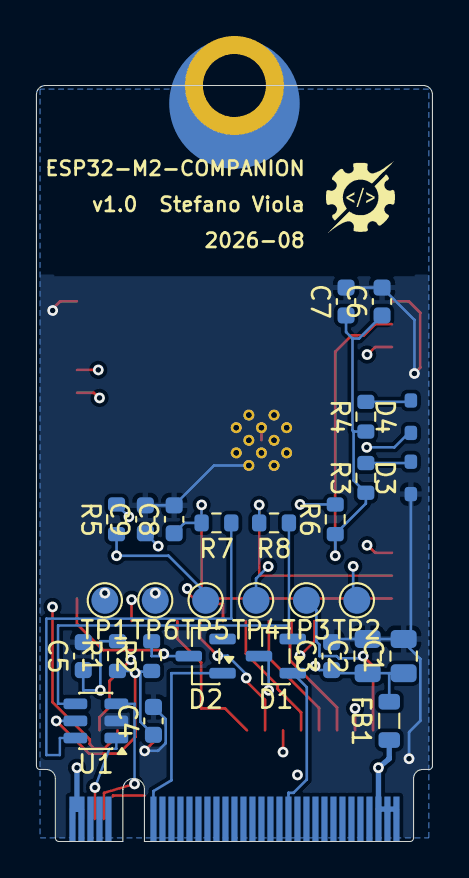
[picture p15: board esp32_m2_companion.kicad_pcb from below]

Board: 4 copper layers, 22.0 x 42.0 mm, 33 parts (29 on the bottom side), 26 nets.

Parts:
C1, C2: 22uF 25V; C_0805_2012Metric
C3, C7: 10uF 10V; C_0603_1608Metric
C4, C6: 100nF 50V; C_0603_1608Metric
C5: 1uF 50V; C_0603_1608Metric
C8, C9: SI-tune; C_0603_1608Metric
D1, D2: BAT54A; SOT-23
D3: green; LED_TJ-S1706_SideView
D4: red; LED_TJ-S1706_SideView
FB1: 100R@100MHz 800mA; L_0805_2012Metric
J1: M2_KEYB_2242_EDGE; M2_KeyB_2242_EdgeFingers
J3: Conn_01x04; JST_SH_BM04B-SRSS-TB_1x04-1MP_P1.00mm_Vertical
J4: Conn_01x08; JST_SH_BM08B-SRSS-TB_1x08-1MP_P1.00mm_Vertical
R1, R2, R5, R6: 10k; R_0603_1608Metric
R3, R4: 330R; R_0603_1608Metric
R7, R8: 0R; R_0603_1608Metric
TP1: TP_EN; TestPoint_Pad_D1.5mm
TP2: TP_BOOT; TestPoint_Pad_D1.5mm
TP3: TP_TXD0; TestPoint_Pad_D1.5mm
TP4: TP_RXD0; TestPoint_Pad_D1.5mm
TP5: TP_3V3; TestPoint_Pad_D1.5mm
TP6: TP_GND; TestPoint_Pad_D1.5mm
U1: USBLC6-2SC6; SOT-23-6
U2: ESP32-S3-WROOM-1; ESP32-S3-WROOM-1_JLC

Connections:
+3V3: C1.1, C2.1, C3.1, C4.1, C6.1, C7.1, FB1.2, J3.2, R1.1, R2.1, R3.1, R4.1, R5.1, R6.1, TP5.1, U1.5, U2.2
+3V3_M2: FB1.1, J1.2, J1.4, J1.70, J1.72, J1.74
EN: C5.1, D1.3, R1.2, TP1.1, U2.3
GND: C1.2, C2.2, C3.2, C4.2, C5.2, C6.2, C7.2, C8.2, C9.2, D3.1, J1.3, J1.5, J1.11, J1.27, J1.33, J1.39, J1.45, J1.51, J1.57, J1.71, J1.73, J3.1, TP6.1, U1.2, U2.1, U2.40, U2.41
IO0_BOOT: D2.3, R2.2, TP2.1, U2.27
IO8: J3.3, R5.2, U2.12
IO9: J3.4, R6.2, U2.17
IO10: J4.3, U2.18
IO11: J4.4, U2.19
IO12: J4.5, U2.20
IO13: J4.6, U2.21
IO14: J4.7, U2.22
IO21: J4.8, U2.23
LED_STATUS_n: D4.1, U2.25
unnamed: D3.2, R3.2
unnamed: D4.2, R4.2
PCIE_1_GPIO_5: D2.1, J1.20
PERST_n: D1.1, J1.50
RXD0: J4.2, TP4.1, U2.36
TXD0: J4.1, TP3.1, U2.37
USBH3_D_N: J1.9, U1.3
USBH3_D_P: J1.7, U1.1
USB_D_N: C9.1, R8.2, U2.13
USB_D_N_ESD: R8.1, U1.4
USB_D_P: C8.1, R7.2, U2.14
USB_D_P_ESD: R7.1, U1.6

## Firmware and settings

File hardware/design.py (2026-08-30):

"""esp32-m2-companion top-level design (SPEC v1, pinmap per docs/pinmap.md).

Build: `uv run python design.py` (or `make check` from repo root).
Outputs in hardware/build/: ERC log, KiCad netlist, XML netlist, BOM.
"""

import os
import sys
from pathlib import Path

HERE = Path(__file__).parent
sys.path.insert(0, str(HERE))

# KiCad 9 libraries (docs/environment.md)
_KICAD_SUPPORT = os.path.expanduser(
    "~/Applications/KiCad/KiCad.app/Contents/SharedSupport")
os.environ.setdefault("KICAD9_SYMBOL_DIR", f"{_KICAD_SUPPORT}/symbols")
os.environ.setdefault("KICAD9_FOOTPRINT_DIR", f"{_KICAD_SUPPORT}/footprints")

from skidl import (ERC, KICAD9, Net, POWER, generate_netlist, generate_xml,
                   set_default_tool)

set_default_tool(KICAD9)

from blocks.esp32s3_companion.esp32s3_companion import esp32s3_companion
from blocks.io_header.io_header import io_header
from blocks.leds.leds import leds
from blocks.m2_keyb_edge.m2_keyb_edge import m2_keyb_edge_template
from blocks.power_3v3.power_3v3 import power_3v3
from blocks.sideband_recovery.sideband_recovery import sideband_recovery
from blocks.usb_esd.usb_esd import usb_esd


def build():
    # --- Nets (names per CLAUDE.md conventions) ---
    gnd = Net("GND")
    gnd.drive = POWER
    v3v3_m2 = Net("+3V3_M2")     # edge side of the ferrite bead
    v3v3_m2.drive = POWER        # supplied by the host slot
    v3v3 = Net("+3V3")           # card rail
    v3v3.drive = POWER

    usbh3_d_p = Net("USBH3_D_P")     # edge side (Mallow net names)
    usbh3_d_n = Net("USBH3_D_N")
    usb_d_p = Net("USB_D_P")         # MCU side of ESD array
    usb_d_n = Net("USB_D_N")

    en = Net("EN")
    io0_boot = Net("IO0_BOOT")
    perst_n = Net("PERST_n")
    pcie_1_gpio_5 = Net("PCIE_1_GPIO_5")
    led_status_n = Net("LED_STATUS_n")
    txd0 = Net("TXD0")
    rxd0 = Net("RXD0")
    header_ios = {n: Net(n) for n in
                  ("IO8", "IO9", "IO10", "IO11", "IO12", "IO13", "IO14",
                   "IO21")}

    # --- M.2 edge fingers (J1) ---
    j1 = m2_keyb_edge_template()(tag="J_M2")
    j1.ref = "J1"
    for p in j1.pins:
        if p.name == "VCC_3V3":
            p += v3v3_m2
        elif p.name == "GND":
            p += gnd
    j1["USBH3_D_P"] += usbh3_d_p
    j1["USBH3_D_N"] += usbh3_d_n
    j1["PERST_n"] += perst_n
    j1["PCIE_1_GPIO_5"] += pcie_1_gpio_5
    # M.2 pin 8 (W_DISABLE1_n) BOOT leg dropped in v1 (ADR 0002 amendment):
    # exposed edge finger, no on-card connection. Recovery on non-Mallow
    # hosts is via TP1(EN)+TP2(BOOT) flying leads.
    j1["W_DISABLE1_n"].do_erc = False

    # --- Blocks ---
    power_3v3(v3v3_m2, v3v3, gnd, tag="blk_power")
    usb_esd(usbh3_d_p, usbh3_d_n, usb_d_p, usb_d_n, v3v3, gnd, tag="blk_usb")
    sideband_recovery(en, io0_boot, perst_n, pcie_1_gpio_5,
                      v3v3, gnd, tag="blk_recovery")
    esp32s3_companion(v3v3, gnd, en, io0_boot, usb_d_n, usb_d_p,
                      led_status_n, header_ios, txd0, rxd0, tag="blk_mcu")
    leds(v3v3, gnd, led_status_n, tag="blk_leds")
    io_header(v3v3, gnd, header_ios, txd0, rxd0, tag="blk_header")


def main():
    build()
    out = HERE / "build"
    out.mkdir(exist_ok=True)
    ERC()
    generate_netlist(file_=str(out / "esp32_m2_companion.net"))
    generate_xml(file_=str(out / "esp32_m2_companion.xml"))
    from tools.gen_bom import write_bom
    write_bom(out)
    print("build outputs in", out)


if __name__ == "__main__":
    main()

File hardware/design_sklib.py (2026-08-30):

from collections import defaultdict
from skidl import Pin, Part, Alias, SchLib, SKIDL, TEMPLATE

from skidl.pin import pin_types

SKIDL_lib_version = '0.0.1'

design = SchLib(tool=SKIDL).add_parts(*[
        Part(**{ 'name':'M2_KEYB_2242_EDGE', 'dest':TEMPLATE, 'tool':SKIDL, 'aliases':Alias({'M2_KEYB_2242_EDGE'}), 'ref_prefix':'J', 'fplist':None, 'footprint':'esp32m2:M2_KeyB_2242_EdgeFingers', 'keywords':None, 'description':'M.2 Key-B 2242 card edge gold fingers (PCB feature)', 'datasheet':None, 'pins':[
            Pin(num='1',name='CONFIG_3',func=pin_types.NOCONNECT),
            Pin(num='2',name='VCC_3V3',func=pin_types.PWRIN),
            Pin(num='3',name='GND',func=pin_types.PWRIN),
            Pin(num='4',name='VCC_3V3',func=pin_types.PWRIN),
            Pin(num='5',name='GND',func=pin_types.PWRIN),
            Pin(num='6',name='FULL_CARD_POWER_OFF_n',func=pin_types.NOCONNECT),
            Pin(num='7',name='USBH3_D_P',func=pin_types.BIDIR),
            Pin(num='8',name='W_DISABLE1_n',func=pin_types.INPUT),
            Pin(num='9',name='USBH3_D_N',func=pin_types.BIDIR),
            Pin(num='10',name='WWAN_LED_n',func=pin_types.NOCONNECT),
            Pin(num='11',name='GND',func=pin_types.PWRIN),
            Pin(num='20',name='PCIE_1_GPIO_5',func=pin_types.INPUT),
            Pin(num='21',name='CONFIG_0',func=pin_types.NOCONNECT),
            Pin(num='22',name='PCIE_1_GPIO_6',func=pin_types.NOCONNECT),
            Pin(num='23',name='PCIE_1_GPIO_11',func=pin_types.NOCONNECT),
            Pin(num='24',name='PCIE_1_GPIO_7',func=pin_types.NOCONNECT),
            Pin(num='25',name='DPR',func=pin_types.NOCONNECT),
            Pin(num='26',name='PCIE_1_GPIO_10',func=pin_types.NOCONNECT),
            Pin(num='27',name='GND',func=pin_types.PWRIN),
            Pin(num='28',name='PCIE_1_GPIO_8',func=pin_types.NOCONNECT),
            Pin(num='29',name='USBH3_SSRX_N',func=pin_types.NOCONNECT),
            Pin(num='30',name='PCIE_1_UIM_RESET',func=pin_types.NOCONNECT),
            Pin(num='31',name='USBH3_SSRX_P',func=pin_types.NOCONNECT),
            Pin(num='32',name='PCIE_1_UIM_CLK',func=pin_types.NOCONNECT),
            Pin(num='33',name='GND',func=pin_types.PWRIN),
            Pin(num='34',name='PCIE_1_UIM_DATA',func=pin_types.NOCONNECT),
            Pin(num='35',name='USBH3_SSTX_N',func=pin_types.NOCONNECT),
            Pin(num='36',name='PCIE_1_UIM_PWR',func=pin_types.NOCONNECT),
            Pin(num='37',name='USBH3_SSTX_P',func=pin_types.NOCONNECT),
            Pin(num='38',name='SDX2AP_STATUS',func=pin_types.NOCONNECT),
            Pin(num='39',name='GND',func=pin_types.PWRIN),
            Pin(num='40',name='PCIE_1_GPIO_0',func=pin_types.NOCONNECT),
            Pin(num='41',name='PCIE_1_L0_RX_N',func=pin_types.NOCONNECT),
            Pin(num='42',name='PCIE_1_GPIO_1',func=pin_types.NOCONNECT),
            Pin(num='43',name='PCIE_1_L0_RX_P',func=pin_types.NOCONNECT),
            Pin(num='44',name='PCIE_1_GPIO_2',func=pin_types.NOCONNECT),
            Pin(num='45',name='GND',func=pin_types.PWRIN),
            Pin(num='46',name='PCIE_1_GPIO_3',func=pin_types.NOCONNECT),
            Pin(num='47',name='PCIE_1_L0_TX_N',func=pin_types.NOCONNECT),
            Pin(num='48',name='PCIE_1_GPIO_4',func=pin_types.NOCONNECT),
            Pin(num='49',name='PCIE_1_L0_TX_P',func=pin_types.NOCONNECT),
            Pin(num='50',name='PERST_n',func=pin_types.INPUT),
            Pin(num='51',name='GND',func=pin_types.PWRIN),
            Pin(num='52',name='PCIE_CLKREQ_n',func=pin_types.NOCONNECT),
            Pin(num='53',name='PCIE_1_CLK_N',func=pin_types.NOCONNECT),
            Pin(num='54',name='PCIE_1_WAKE_n',func=pin_types.NOCONNECT),
            Pin(num='55',name='PCIE_1_CLK_P',func=pin_types.NOCONNECT),
            Pin(num='56',name='RFFE_CLK',func=pin_types.NOCONNECT),
            Pin(num='57',name='GND',func=pin_types.PWRIN),
            Pin(num='58',name='RFFE_DATA',func=pin_types.NOCONNECT),
            Pin(num='59',name='LAA_TX_EN',func=pin_types.NOCONNECT),
            Pin(num='60',name='WLAN_TX_EN',func=pin_types.NOCONNECT),
            Pin(num='61',name='ANTCTL1',func=pin_types.NOCONNECT),
            Pin(num='62',name='COEX_RXD',func=pin_types.NOCONNECT),
            Pin(num='63',name='ANTCTL2',func=pin_types.NOCONNECT),
            Pin(num='64',name='COEX_TXD',func=pin_types.NOCONNECT),
            Pin(num='65',name='RFFE_VIO_1V8',func=pin_types.NOCONNECT),
            Pin(num='66',name='PCIE_1_UIM_CD',func=pin_types.NOCONNECT),
            Pin(num='67',name='M2_CARD_RESET_n',func=pin_types.NOCONNECT),
            Pin(num='68',name='AP2SDX_STATUS',func=pin_types.NOCONNECT),
            Pin(num='69',name='CONFIG_1',func=pin_types.NOCONNECT),
            Pin(num='70',name='VCC_3V3',func=pin_types.PWRIN),
            Pin(num='71',name='GND',func=pin_types.PWRIN),
            Pin(num='72',name='VCC_3V3',func=pin_types.PWRIN),
            Pin(num='73',name='GND',func=pin_types.PWRIN),
            Pin(num='74',name='VCC_3V3',func=pin_types.PWRIN),
            Pin(num='75',name='CONFIG_2',func=pin_types.NOCONNECT)] }),
        Part(**{ 'name':'FerriteBead', 'dest':TEMPLATE, 'tool':SKIDL, 'aliases':Alias({'FerriteBead'}), 'ref_prefix':'FB', 'fplist':[''], 'footprint':'Inductor_SMD:L_0805_2012Metric', 'keywords':'L ferrite bead inductor filter', 'description':'Ferrite bead', 'datasheet':'~', 'pins':[
            Pin(num='1',name='~',func=pin_types.PASSIVE,unit=1),
            Pin(num='2',name='~',func=pin_types.PASSIVE,unit=1)], 'unit_defs':[] }),
        Part(**{ 'name':'C', 'dest':TEMPLATE, 'tool':SKIDL, 'aliases':Alias({'C'}), 'ref_prefix':'C', 'fplist':[''], 'footprint':'Capacitor_SMD:C_0805_2012Metric', 'keywords':'cap capacitor', 'description':'Unpolarized capacitor', 'datasheet':'~', 'pins':[
            Pin(num='1',name='~',func=pin_types.PASSIVE,unit=1),
            Pin(num='2',name='~',func=pin_types.PASSIVE,unit=1)], 'unit_defs':[] }),
        Part(**{ 'name':'USBLC6-2SC6', 'dest':TEMPLATE, 'tool':SKIDL, 'aliases':Alias({'USBLC6-2SC6'}), 'ref_prefix':'U', 'fplist':['Package_TO_SOT_SMD:SOT-666', 'Package_TO_SOT_SMD:SOT-23-6'], 'footprint':'Package_TO_SOT_SMD:SOT-23-6', 'keywords':'usb ethernet video', 'description':'Very low capacitance ESD protection diode, 2 data-line, SOT-23-6', 'datasheet':'https://www.st.com/resource/en/datasheet/usblc6-2.pdf', 'pins':[
            Pin(num='1',name='I/O1',func=pin_types.PASSIVE,unit=1),
            Pin(num='3',name='I/O2',func=pin_types.PASSIVE,unit=1),
            Pin(num='5',name='VBUS',func=pin_types.PASSIVE,unit=1),
            Pin(num='2',name='GND',func=pin_types.PASSIVE,unit=1),
            Pin(num='6',name='I/O1',func=pin_types.PASSIVE,unit=1),
            Pin(num='4',name='I/O2',func=pin_types.PASSIVE,unit=1)], 'unit_defs':[] }),
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

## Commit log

2026-08-28 Phase 0: pinmap for GATE 1 review + risk register update
    - M.2 Key-B table cross-checked Mallow V1.1 vs Quectel RM50xQ (WWAN standard)
    - EN<-PERST#(50), BOOT<-pin20(+pin8 diode-OR), Schottky isolation for 1.8V hosts
    - ESP32-S3 allocation keeps strapping + octal-PSRAM pins off the header
2026-08-28 GATE 1: record owner decisions as ADRs 0002-0004, resolve R1/R4
    - EN<-PERST#(50), BOOT<-diode-OR(20,8) approved; SODIMM 244 GPIO usability
    verified in mainline verdin dtsi for iMX8MP/iMX8MM/AM62
    - Status LED: plain LED on IO48 (WS2812 rejected)
    - RPi5 demoted to nice-to-have
2026-08-28 Phase 1: schematic-as-code in SKiDL — all blocks, ERC clean, netlist+BOM+block PDFs
    - ADR 0001: SKiDL over atopile (CLI deprecated to SaaS)
    - 7 blocks per SPEC $12 layout; runtime symbol-vs-datasheet pin asserts
    - ERC: 0 errors / 0 warnings; netlist verified net-by-net vs pinmap
    - BOM 14 lines, 3 Extended (module, ST USBLC6, BAT54A) all justified
    - make check / make svg targets
    [design.py, design_sklib.py, gen_bom.py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]
2026-08-28 GATE 2: ESD array sourcing — ST C7519 primary, UMW C2687116 second source
2026-08-28 Phase 2 groundwork: M.2 mechanical sources secured, JLCPCB gold-finger findings
    - M.2 EM Spec Rev 1.0 (archive.org) stored — resolves R8
    - Vendored hardware-verified Key-B 2242 card footprint (timonsku, CERN-OHL-P)
    - Amphenol MDT420B01001 product brief (Mallow socket ratings)
    - R2: JLCPCB does gold fingers on 0.8mm but bevel is 30° and needs ≥50x50mm
    panel with fingers on panel edge — GATE 3/4 decision required
2026-08-28 Phase 2: verify Key-B 2242 edge footprint vs EM spec Fig 19, rename pads to netlist numbering
2026-08-28 GATE 2 adversarial review fixes + Phase 2 board generation
    Review (19 agents, findings log updated):
    - Fix false 'diode blocks' claim: host sidebands must idle OD/Hi-Z or
    VOH>=2.8V; ADR 0002 amended; risks R9/R10 added
    - Relabel cap voltages (C19702=10V, C15849=50V); fix pinmap misquotes on
    NC pins (38/41/43/47/49/56/58/60/64/68); 11 GND fingers not 12
    - Add HDG USB provision R7/R8 (0R series) + C8/C9 (DNP shunt)
    - gen_bom: DNP parts can no longer leak into assembly CSV
    - Explicit stable designators on every part
    Board:
    - gen_pcb.py: netlist->kicad_pcb via kinet2pcb (KiCad python), 4L/0.8mm,
    placement proposal, USB_DIFF netclass (impedance TBD), antenna keepout,
    JLCPCB DRC minima, k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
    [esp32_m2_companion.kicad_pcb]
2026-08-28 ADR 0005: JST SH connectors (Qwiic + SH-8) replace 2.54 header; top/bottom re-split; 3D outputs
    - io_header: J3=SM04B-SRSS-TB (C160404) Qwiic, J4=SM08B-SRSS-TB (C160407)
    - top = module + connectors; bottom = passives/ESD/LEDs/TPs (connector
    courtyards consume the lower top zone - documented in layout-notes)
    - R11: M.2 height envelope violation (module 3.1mm) accepted for open slots
    - DRC: no shorts/clearance errors; GLB export + raytraced renders
    [esp32_m2_companion.kicad_pcb]
2026-08-28 ADR 0005 amendment: vertical JST SH (BM04B/BM08B) — side-entry unmatable in-slot
    [esp32_m2_companion.kicad_pcb]
2026-08-28 Generated KiCad schematic (make sch): title block, git rev, CERN-OHL-P v2
    - tools/gen_sch.py: SKiDL -> .kicad_sch, global-label style (no crossing
    wires), embedded lib symbols (extends resolved), custom edge symbol,
    DNP marks, block group headings
    - LICENSE: CERN-OHL-P v2 (owner: open source); README credits
    - netlistsvg demoted to auxiliary (ADR 0001 amendment, PROCESS finding)
    [gen_sch.py]
2026-08-28 gen_sch: orientation-true labels + per-side stagger stubs
    - label direction from the pin's own orientation (position-derived logic
    put vertical labels on tall symbols' end pins)
    - adjacent 2.54mm-pitch labels staggered 0/6.35mm with wire stubs;
    vertical sides get base offset + 3-step cycle (stacked GND/3V3 pins)
2026-08-29 gen_sch: eliminate vertical labels — L-stubs to horizontal labels on vertical pins
    - down/up-pointing pins get a drop + right-bend stub ending in a normal
    horizontal global label; stacked same-x pins (module GNDs) share the
    riser with increasing drops
    - value text moves above the symbol on parts with vertical pins so stubs
    never cross it (owner-reported overlaps: TPs, BAT54A pin 3, module GND/3V3)
2026-08-29 DATASHEET.md: generated product datasheet (make datasheet)
    - pin/connector tables extracted from the SKiDL circuit (cannot drift)
    - specs cite stored reference datasheets (WROOM v1.8 tables 1-1/6-4/7-x)
    - block diagram (mermaid), recovery sequence, host compatibility, R11 note
    [gen_datasheet.py]
2026-08-29 Socket-zone fix (owner-caught) + datasheet mechanical/product views
    - EM spec Figs 38/39: mated socket covers first 4.8mm of card both faces;
    U1/C4/FB1/J3/J4 were inside it — re-placed, courtyard added to edge
    footprint so DRC enforces the zone permanently
    - JST eSH catalog stored: BM header 4.2mm tall (~6.3 mated) = card max height
    - gen_views.py: Mallow-style labeled top/bottom views + dimensioned
    mechanical drawing, callout legends shared with gen_datasheet
    - DATASHEET.md: product views + mechanical data sections, corrected heights
    [esp32_m2_companion.kicad_pcb]
2026-08-29 Side-view LEDs at left card edge (owner-caught: top-emitting invisible in-slot)
    - D3/D4 -> TOGIALED TJ-S1706SW6T side-view (C273616/C273612), 330R series
    - corrected wrong orientation claim in layout-notes (card top faces AWAY
    from host; bottom faces host at ~2.5mm)
    - ADR 0003 amended; datasheet/views regenerated
    [esp32_m2_companion.kicad_pcb]
2026-08-29 Docs sweep for side-view LED change: pinmap, block refs, datasheet provenance
    - pinmap §2 IO48 row updated (WS2812 alternative long-rejected)
    - blocks/leds/datasheets.md: TOGIALED parts + GATE 3 land-pattern check
    - TOGIALED drawing fetch blocked from this machine -> noted in provenance
    - all generated artifacts rebuilt (sch/datasheet/renders/views/GLB)
2026-08-29 docs/3d: self-contained 3D viewer + GLB + STEP in the repo (make 3d)
    The interactive viewer previously existed only as a private claude.ai
    artifact; now committed (offline single-file HTML, embedded GLB) with
    STEP/GLB for MCAD and a regeneration target.
    [esp32_m2_companion.step]
2026-08-29 docs/3d: STL for GitHub native 3D preview; Pages URL in README; make 3d builds STL
    [esp32_m2_companion.stl]
2026-08-30 Phase 2 routing: USB diff-pair + planes + 27/28 nets (scripted route.py)
    - tools/route.py: hand-routed 90ohm USB pair (0.14/0.14, L2-referenced),
    freerouting for remaining signals, 4 plane pours, EPAD via grid, GND stitch
    - 27/28 nets routed & DRC-clean vs JLCPCB minima; 1 net (W_DISABLE1_n,
    secondary BOOT strap) left for interactive finish — see docs/routing-status.md
    - USB_DIFF geometry from JLC04081H-3313 stackup (verify at order via impedance tool)
    [esp32_m2_companion.kicad_pcb]
2026-08-30 docs: routing method + PROCESS finding (avoid the autorouter-loop rabbit hole)
    Captures the hard-won method after ~28 wasted autorouter runs: hand-route +
    lock congested/critical nets once, autoroute easy nets once, finish by hand
    without re-autorouting; read real pad extents; verify edits apply. Candidate
    rule for the shared hardware-design skill (SPEC 12).
2026-08-30 Phase 2 routing: clean base, USB pair intact, 27/28 nets (W_DISABLE1_n for GUI)
    - reverted the D+ fan-west experiment that broke the USB pair; USB pair
    back to known-good 90ohm route
    - 27/28 nets routed, DRC clean of real shorts (3 benign J1 artifacts only)
    - W_DISABLE1_n (secondary BOOT strap) left as one interactive track;
    method + waypoints in docs/routing-status.md
    [esp32_m2_companion.kicad_pcb]
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2026-08-30 Board fully routed (all signal nets) + pin-8 (W_DISABLE1_n) dropped in v1
    ROUTING: root cause of the multi-run saga was too few freerouting passes
    (cut to 6 for speed; hard recovery nets need ~50+). Restored to 80 passes ->
    all 27 signal nets route, USB 90ohm pair hand-locked, 4 planes poured, EPAD
    via grid. DRC: no real shorts; residual = GND zone-island + 3 J1
    footprint-internal notes (all benign).
    PIN 8 DROP (ADR 0002 amendment): W_DISABLE1_n BOOT leg removed - unroutable
    in the pin 7/8/9 interleave AND redundant with TP1(EN)+TP2(BOOT) flying-lead
    recovery. D2 pin 2 = NC; edge finger exposed/unconnected. Mallow recovery
    (pin 50 + pin 20) intact.
    Regenerated from sources: schematic PDF,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
    [esp32_m2_companion.kicad_pcb, esp32_m2_companion.step, esp32_m2_companion.stl]
2026-08-30 Phase 3: JLCPCB fab package (make fab) — gerbers.zip + BOM + CPL + order checklist
    - gen_fab.py: gerbers+drill zip, JLC-format CPL (22 placed; DNP/edge/TPs
    excluded), BOM copy; publishes upload files to fab/
    - fab/README.md: which file goes where + v1 order settings (4L/0.8mm/ENIG,
    impedance ON, both-sides assembly, ENIG not special gold-fingers)
    [esp32_m2_companion_bom_jlc.csv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]
2026-08-30 docs: verify USB 90Ω pair on JLC04081H-3313; finalize v1 JLC order settings
    Confirmed against JLCPCB's live impedance calculator (2026-08-30): on the
    Standard 0.80 mm JLC04081H-3313 stackup, 90 Ω differential needs 5.2 mil width
    vs our 0.14 mm (~88 Ω, inside ±10%) — no board change. Drop the paid impedance-
    control QC option (FS-USB doesn't need it; specifying the stackup already pins
    the geometry). Record Gold Fingers=Yes / no bevel (<50 mm) + hand-chamfer note.
2026-08-30 silk: add bottom-side board label + Samnium Tech logo
    Name / v1.0 / Stefano Viola / 2026-08 plus the gear logomark in the top strip
    (under the mounting hole, above C6/C7). Logo traced from the hi-res company
    logo to smooth silk polygons (branding/gen_logo_silk.py -> logo_silk_rects.json),
    applied by tools/add_silk.py (grouped 'silk_label', idempotent, never touches
    copper/routing). DRC clean — only the pre-existing benign J1/GND-island notes.
    Regenerated renders, 3D (GLB/STEP/STL/viewer) and datasheet views from the
    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
    [esp32_m2_companion.kicad_pcb, esp32_m2_companion.step, esp32_m2_companion.stl]
2026-08-30 docs: drop broken STL native-preview link from README; unstale render caption
    The GitHub-native STL viewer mis-renders (board sits ~100mm off origin, and STL
    carries no color/silk anyway). Keep the STL file + `make 3d` (useful mesh), just
    remove the misleading README link. Also correct the hero caption ("pre-route" ->
    routed board).
2026-08-30 leds: replace 0603 placeholder with real TJ-S1706 side-view land pattern
    The D3/D4 footprint was a generic 0603 (1.576 mm c-c) — too tight for the
    1.70 mm TJ-S1706 body. Built custom LED_TJ-S1706_SideView (pads 0.80x0.70,
    1.80 mm c-c) from the datasheet (now vendored) and swapped D3/D4 to it on the
    routed board + refilled zones. Verified against the datasheet:
    - Polarity: pin 1 = cathode (black-mark end / diode symbol), pin 2 = anode —
    matches KiCad Device:LED and the netlist. No net changes.
    - Connectivity preserved: old track ends fall inside the new pads (<=53um);
    DRC 57 violations vs 58 before (all pre-existing benign J1/GND/silk notes),
    zero clearance/dangling/text-height adde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
    [esp32_m2_companion.kicad_pcb, esp32_m2_companion.step, esp32_m2_companion.stl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]
2026-08-31 docs: remove stale routing-status.md
    The board is fully routed; its "1 remaining net" (W_DISABLE1_n / M.2 pin 8) was
    later dropped, so the doc's remaining-work section + GUI walkthrough are moot,
    and "27 of 28 nets" is wrong. Everything still valid lives in routing-method.md
    (method), stackup.md (USB pair / planes / antenna), and layout-notes.md (benign
    J1 DRC notes). Repointed the fab/README reference to layout-notes.md.
2026-09-01 lessons(m2_keyb_edge): plated mounting half-hole -> $38 castellation fee
    JLCPCB review flagged the M.2 mounting semicircle (PTH, centred on the top
    edge) as an unselected castellated hole; castellated processing cost $38 flat
    on v1. The hole carries no net (purely mechanical), so rev B (+ the RP2350
    sibling reusing this edge) should make it NPTH to drop the fee.
2026-09-02 lessons(m2_keyb_edge): USB via/GND stub in B-key notch masked by dru
    JLCPCB production-file review flagged copper (a host-USB via pad + a redundant
    GND stub) at the B-key notch that our DRC missed: the .kicad_dru waives
    edge_clearance for ALL J1 members (for the gold fingers), which also suppressed
    this real warning. Barrel is 0.15mm clear so v1 proceeds; rev B pulls the via
    inboard, drops the stub, and narrows the dru waiver to finger pads only.
2026-10-05 docs: v1 bring-up log + LED-reversal findings
2026-10-05 drc: scope J1 edge waiver to finger pads, 0.3 mm edge clearance, make drc gate
    Rev A waived edge_clearance for memberOfFootprint('J1'); J1 owns the
    whole Edge.Cuts outline, so the waiver disabled edge clearance
    board-wide and hid the USBH3_D_N via milled away in the B-key notch.
    min_copper_edge_clearance was also 0.0. Now: waiver only for J1 SMD
    pads, 0.3 mm global. make drc fails on any non-excluded violation.
    Intentionally red: flags the v1 notch copper + mounting-hole copper
    (fixed in following commits).
2026-10-05 m2_keyb_edge: mounting notch NPTH, drop unconnected B.Cu ring/square
    Half-cut plated hole triggered JLC castellation ($38 flat) on rev A;
    it carried no net. Library footprint and board instance both changed
    (DRC lib parity confirms they match). Registers the esp32m2 footprint
    library in fp-lib-table so DRC can check parity at all.
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2026-10-05 fab: JLC rotation table + polarity guard; CPL from generated BOM
    - JLC_ROT: per-LCSC rotation offset + preview-verified date. D3/D4
    (TJ-S1706) +180 deg - v1 at +0 was assembled reversed.
    - make fab exits 2 (ORDER BLOCKED) until every polarized part's
    rotation is verified against the JLC placement preview.
    - polarity_report.py asserts each LED anode is the resistor-side pad
    (netlist + geometry; negative-tested with D3 rotated 180) and writes
    fab/polarity_checklist.md - what the preview must show, in N/S terms
    that survive the bottom-side mirror.
    - placed set = generated BOM (DNP enforced by gen_bom); drops the
    hand-kept DNP list.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
2026-10-05 lessons: rev-B corrections (notch via was severed, GND islands, waiver scope)
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2026-10-06 tools: skip KiCad-Python finalization (macOS 'Python quit unexpectedly')
    KiCad 9.0.9's bundled Python 3.9 segfaults in Py_FinalizeEx after
    pcbnew scripts finish (crash reports: GC visit_decref in finalize).
    Results were never affected, but macOS showed a crash dialog per run.
    All pcbnew tools now exit via kicad_exit.run()/hard_exit() (flush +
    os._exit), preserving exit codes.
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2026-10-06 silk: rev-B label pass - LED cathode bars, TP function labels, connector legends
    - LED_TJ-S1706_SideView: silk cathode bar (pad 1 = black-mark end);
    v1 had no silk polarity mark on D3/D4. Board instances re-synced
    (DRC library parity confirms).
    - TP1-6 silk shows function (EN BOOT TX RX 3V3 GND); TPn refs on B.Fab.
    - J3/J4: legends 'J3 QWIIC' / 'J4 UART/SPI' beside the pin-1 arrows
    (per-pin labels can't be legible at 0.8 mm on 1.0 mm pitch; J3 pins
    2/3 sit over the B-key notch). Proposal for owner label review.
    - All refs 0.8/0.153 mm (board min_text_height), placed by collision
    search; R2 and U2 refs are fab-only (no legal silk spot).
    - Board text v1.0/2026-08 -> v2.0/2026-10 (pro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
2026-10-06 datasheet: rev-B labels - pin 8 restored, NPTH notch, no bevel, silk markings
    Corrects two v1 label errors: mounting notch was never a 'plated GND
    pad' (no net), and the fingers were never bevelled (JLC can't bevel
    <50 mm boards; fab/README).
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2026-10-06 labels: generated label inventory (make labels); fab/README for rev B
    - tools/label_inventory.py: refdes/values, every net with its naming
    source + rule check, every silk text, polarity/pin-1 markers with CPL
    rotation, connector pinouts, TPs, fab notes - generated from netlist
    + board for the owner's GATE B2 label review.
    - fab/README.md: rev-B order notes - castellated = No (NPTH notch, own
    drill file), polarity-preview procedure, ORDER BLOCKED semantics,
    Extended list corrected (v1 omitted the LEDs).
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2026-10-06 GATE B2 decisions: net renames, board text v1.0 Rev B
    - L1: SKiDL auto nets N$1/N$2 -> LED_PWR_A / LED_STATUS_A (named in
    leds block).
    - L2: IO0_BOOT -> IO0 (WROOM-1 pin name per CLAUDE.md naming rule);
    blocks, design.py, route.py, gen_svg/gen_datasheet updated.
    Board: exact net-name strings renamed; netlist<->board pad parity
    121/121.
    - L5: board text 'Stefano Viola' / 'v1.0 Rev B 2026-10' - fixes only,
    major number reserved for feature additions (owner). Drawings,
    fab/README titles follow.
    - Label inventory records all GATE B2 decisions (L1-L8).
    make check: ERC clean. make drc: 0 violations, 0 unconnected.
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2026-10-06 docs: rev-B documentation audit - correct every stale v1 statement
    Audit of all hand-written docs + block docstrings against the Rev B
    state (pin 8 restored, IO0/LED_* net names, R3 100R, NPTH notch, no
    bevel, LED CPL +180, notch via fix, GND-island vias, DRC policy, make
    targets, v1.0 Rev B naming, unit serial):
    - README: revision + status table (v1 defects -> Rev B fixes), build
    targets, review/bring-up/fab links, Mallow validated, height note.
    - pinmap: pin 8 BOOT input restored, IO0 diode-OR 20+8, J3/J4 replace
    the old 12-pin header, status.
    - risks: R2 resolved (no bevel), R8 done, R9 not observed at bring-up,
    R10 row repaired, R11 noted.
    - layout-notes: historical banner + correc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
2026-10-06 leds: simple 3D model for the side-view LED (D3); link D3/D4 to their library
    - 3dmodels/LED_TJ-S1706_SideView.wrl: 1.70x0.60x1.10 mm body, lens on
    the emitting face, end terminals (renders showed bare pads).
    - D3/D4 board instances had no library nickname, so DRC library parity
    never checked them (corrects an earlier claim, see findings). Linked
    to esp32_m2_companion:LED_TJ-S1706_SideView; parity passes.
    make drc: 0 violations, 0 unconnected.
2026-10-06 docs: SPEC §13 amendments (no bevel, revision naming), CLAUDE.md workflow, routed notch wording
    - SPEC.md: new §13 Amendments (owner, 2026-10-06): A1 no edge bevel
    (JLC < 50 mm limit; supersedes §5/§9 wording), A2 revision naming
    (fix-only = v1.0 Rev B; major = features; tag the ordered commit).
    - CLAUDE.md: make drc / drawings / labels / fab (ORDER BLOCKED) workflow,
    KiCad-Python rules, DRC waiver policy, no bevel, revision + net naming,
    unit serial.
    - All current-state docs/tools: notch is routed in the outline (no drill,
    no plating, no copper) - replaces the interim 'NPTH' wording; fab sheet
    annotates the R1.75 routed notch.
    - Remove orphan v1 images board_routed_iso.png,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
2026-10-06 fab/README: castellation flag on rev B = something wrong (no plated edge features)
2026-10-09 tools: make jlc-check - verify JLC's processed production files before confirming
    Compares JLC's 'Confirm Production File' zip with fab/: stored upload
    byte-identical (SHA-256), every drill hole matched after locating the
    card in their panel (any missing/resized/extra hole = FAIL), and each
    layer rendered at 50 px/mm with red/blue diff images + mm^2. Lists the
    expected CAM adjustments (etch compensation, plane pull-back at V-cut,
    finger-tip cut-back, mask window over fingers, silk clipped off pads).
    First use (Rev B): PASS - 57/57 holes, only standard CAM adjustments.
    fab/README order steps updated: the pre-order preview is automatic and
    for reference only; the real checks are the productio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
2026-10-13 GATE B3: side-view LED lens/polarity mismatch (JLC engineering); correct v1 note
    JLC engineering (physical parts, tape direction): on our footprint the
    TJ-S1706 gives either correct polarity with the lens facing inward, or
    lens to the edge with reversed polarity. Rotation can't fix it. Corrects
    the v1 conclusion that hand-rotating D4 restored the emit direction (only
    polarity was verified). Owner decision for Rev B: correct polarity, lens
    inward. Next revision must fix the footprint/part relationship.
    Rest of the final DFM and the production files verified.
2026-10-13 fab: JLC_ROT verified against JLC's final DFM (GATE B3); J4 +180
    All polarized parts dated 2026-10-13 from the engineers' final placement:
    - D3/D4 +180 = correct polarity (lens inward with this footprint, see
    review-findings GATE B3).
    - J4 (C160394) +180: at +0 JLC's automatic preview put pin 1 at the
    opposite end from J3; their engineers rotated it 180 in the final DFM.
    The CPL now matches what is being built, so the next order doesn't
    depend on that manual correction. (Rev B was ordered at +0.)
    - D1/D2, U1, J3, U2 unchanged at +0.
    make fab now exits 0 (no longer ORDER BLOCKED). Gerbers unchanged (the
    regenerated zip differed only in timestamps; the ordered zip is kept).
    Co-Author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
